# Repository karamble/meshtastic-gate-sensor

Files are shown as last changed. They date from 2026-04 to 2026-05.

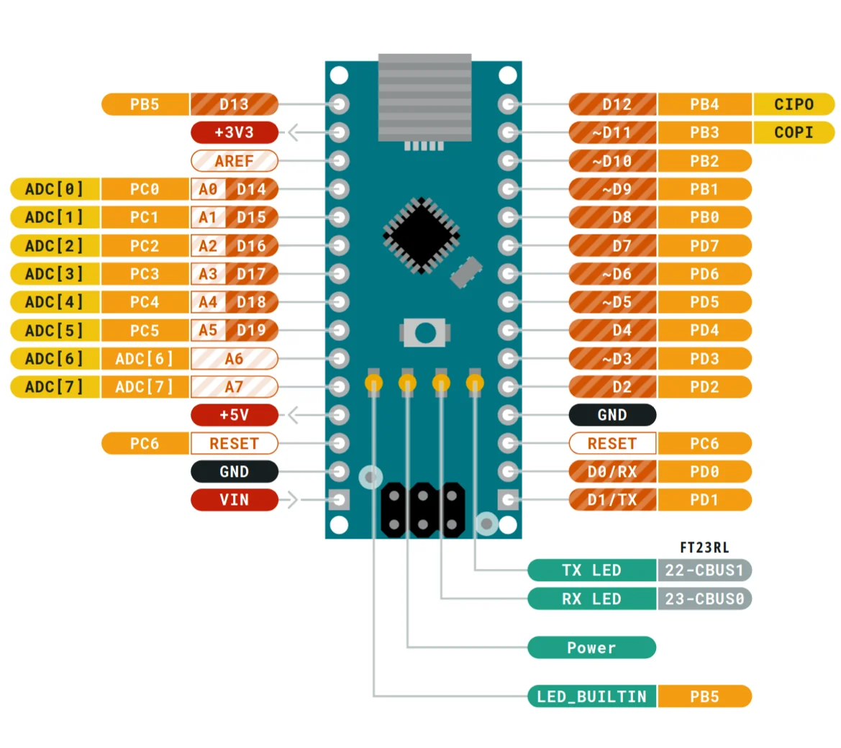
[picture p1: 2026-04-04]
pin-outs/arduino-nano.webp

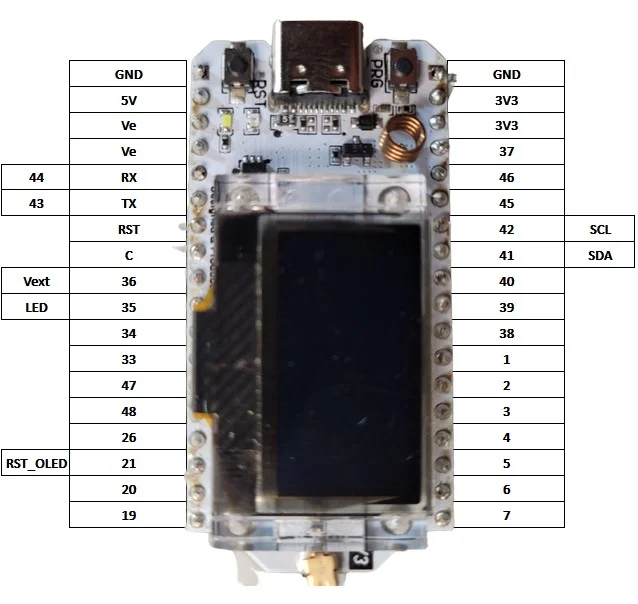
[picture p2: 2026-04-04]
pin-outs/heltecv3.webp

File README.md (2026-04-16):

# Meshtastic Gate & Door Sensor

Carrier board + firmware that bridges a cheap 433 MHz wireless door sensor onto a private Meshtastic LoRa mesh. A trigger on the door raises an event on the mesh — no WiFi, no cloud, no gateway.

## Architecture

```
KERUI D026 (433 MHz) → RXB6 Receiver → Arduino Nano → UART → Heltec LoRa32 V3 → LoRa mesh
```

The 433 MHz sensor broadcasts a fixed code on every open/close event. An Arduino Nano decodes the code with `rc-switch` on D2 (INT0) and forwards a short text line over SoftwareSerial D3 → voltage divider → Heltec GPIO47. The Heltec runs stock Meshtastic with the serial module in `TEXTMSG` mode at 9600 baud and relays each line into the mesh. A 10 s debounce collapses the KERUI retransmit burst into one mesh event per physical opening.

Firmware emits `Gate: TRIGGERED` on every event and `GATE NODE: Online` every 5 minutes as a heartbeat. KERUI D026 sends the same code on open and close, so `CODE_CLOSED` is disabled by default — one code per event is all you get.

Powered by a Waveshare Solar Power Manager D with 2× 18650 batteries and a 6 V 2 W solar panel. Total draw ≈ 105 mA.

## Carrier PCB v2.3

Custom 75×66 mm 2-layer board with:

- Heltec LoRa32 V3 socket (2×18 pins)
- Arduino Nano socket (2×15 pins, 15.24 mm row spacing)
- RXB6 433 MHz receiver (8-pin SIP, direct solder)
- Logic level divider 2.2k / 3.3k (5V → 3.0V on GPIO47)
- Hardening: 10k DE pull-up, 100nF bypass, 100µF bulk
- GND copper pour on both layers
- 0 DRC violations, 34 netlist self-checks pass

Generated programmatically by `pcb/gate_sensor_pcb_v2.py` and validated with KiCad 10.

## Build

Requires Docker (for KiCad CLI) and PlatformIO.

```bash
make help            # show all targets

# PCB
make drc             # design rule check
make fab             # export Gerbers + drill for JLCPCB

# Firmware
make build           # compile
make upload          # flash the Nano
make monitor         # 115200 USB serial monitor
make learn-sensor    # discover a new 433 MHz sensor's code

# Heltec Meshtastic flash & configure (stock firmware)
./scripts/flash-heltec-meshtastic.sh           # defaults (auto-detect, EU_868)
./scripts/flash-heltec-meshtastic.sh --help
```

The flash script downloads the latest stock Meshtastic release, flashes the Heltec V3, applies the gate-sensor config (GPIO47 RX at 9600 baud, TEXTMSG mode, owner name `GateSensor`/`GATE`, GPS disabled, Bluetooth disabled) and verifies every setting before closing.

## Learning a new sensor

If you're using a different 433 MHz sensor than the KERUI D026, discover its code with:

```bash
make learn-sensor
```

Trigger the sensor a few times and watch for repeating `RF unknown: <decimal>` lines. Copy the decimal into `CODE_OPEN` in `firmware/include/config.h`, re-run `make upload`, and the sensor will fire `Gate: TRIGGERED` on the mesh. See [docs/learn-sensor.md](docs/learn-sensor.md) for details.

## Project Structure

```
├── Makefile                      # build targets (KiCad Docker + PlatformIO)
├── pcb/
│   ├── gate_sensor_pcb_v2.py     # PCB generator script
│   ├── gate_sensor_v2.kicad_pcb  # generated board
│   ├── test_netlist.py           # 34-check PCB self-test
│   ├── generate_assembly.py      # 3D assembly view generator
│   └── logo_silk.json            # raccoon logo silkscreen data
├── firmware/
│   ├── platformio.ini            # PlatformIO config (board=nanoatmega328new)
│   ├── src/main.cpp              # bridge firmware
│   └── include/config.h          # sensor codes, pin defs, timing
├── scripts/
│   └── flash-heltec-meshtastic.sh  # Heltec flash + config
├── docs/
│   ├── schematic.md              # schematic + netlist
│   ├── pcb.md                    # PCB design documentation
│   ├── firmware.md               # firmware documentation
│   ├── assembly.md               # assembly and setup guide
│   ├── learn-sensor.md           # discovering a new 433 MHz sensor code
│   ├── bom.md                    # bill of materials
│   └── ordering.md               # JLCPCB ordering guide
└── pin-outs/                     # component pinout reference images
```

## BOM

~$52 total for one complete sensor node. See [docs/bom.md](docs/bom.md) for the full bill of materials.

## License

ISC — see [LICENSE](LICENSE).

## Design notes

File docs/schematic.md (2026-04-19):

# Schematic Description

## Architecture

```
  KERUI D026          RXB6 433MHz        Arduino Nano           Heltec LoRa32 V3
  door sensor         receiver           (ATmega328P)           (Meshtastic)
  +-----------+       +----------+       +----------------+     +----------------+
  | 433 MHz   |~~~~~> | DATA  ---|------>| D2 (INT0)      |     |                |
  | open/close|       | DE <-R5- |--+    |                |     |                |
  +-----------+       | VDD      |  |    | D3 (TX)  ------|--+  |                |
                      | GND      |  |    |                |  |  |                |
                      +----------+  |    | D4 (RX) <------|--|--|- GPIO48 (TX)   |
                                    |    |           5V --|--|--|- 5V            |
                                    |    |          GND --|--|--|- GND           |
                                    |    +----------------+  |  |                |
                                    |                        |  |                |
                                    |    Logic Level Div     |  |                |
                                    |    +------------+      |  |                |
                                    |    | R1 2.2k    |<-----+  |                |
                                    |    |   +--jct---|-------->| GPIO47 (RX)   |
                                    |    | R2 3.3k    |         |                |
                                    |    |   +--GND   |         |                |
                                    |    +------------+         +----------------+
                                    |
  Waveshare Solar     J4 (switch)   |
  Power Mgr D         +-----+       |
  +-----------+  J2   |IN|OUT|------+----> 5V bus
  | 5V OUT  --|------->  |   |
  | GND     --|------>| GND bus
  +-----------+       +-----+
```

## Net List

| Net | Description | Connected Pins |
|-----|---|---|
| GND | Ground | Heltec L1, R1; Nano L4, R14; RXB6 pins 2,3,8; R2 pad2; C1 pad2; C2 pad2; J2 pin2 |
| 5V | Main power bus | Heltec L2; Nano R12 (5V pin); RXB6 pins 4,5 (VDD); R5 pad1; C1 pad1; C2 pad1; J4 pin2 (switch out) |
| 5V_IN | Unswitched input | J2 pin1 (Waveshare 5V); J4 pin1 (switch in) |
| 3V3 | 3.3V (Heltec only) | Heltec R2, R3 (bridged, not distributed) |
| D3 | SoftwareSerial TX | Nano R10 (D3); R1 pad1 |
| D2 | RF DATA | Nano R11 (D2/INT0); RXB6 pin 7 (DATA) |
| HELTEC_RX | Level-shifted serial | R1 pad2; R2 pad1; Heltec L13 (GPIO47) |
| HELTEC_TX | Heltec serial TX (direct, v2.5) | Heltec L14 (GPIO48); Nano R9 (D4) |
| DE | RXB6 data enable | RXB6 pin 6 (DE); R5 pad2 |

**Note on D2 net:** This signal connects to physical pin D2 (L5), which provides INT0 for RCSwitch interrupt-driven reception. The firmware uses `RF_PIN 2` (D2).

## Pin Assignments

### Heltec WiFi LoRa 32 V3 (U3) — 2x18 pins

Left row (L1-L18), top to bottom (USB end to antenna end):

| Pin | Label | Net | Function |
|-----|---|-----|---|
| L1 | GND | GND | Ground |
| L2 | 5V | 5V | Power input (from 5V bus) |
| L3 | Ve | -- | |
| L4 | Ve | -- | |
| L5-L12 | GPIO44,TX43,RST,... | -- | Unused |
| L13 | GPIO47 | HELTEC_RX | **Serial RX** (Meshtastic serial module) |
| L14 | GPIO48 | HELTEC_TX | **Serial TX** (Meshtastic serial module) → Nano D4 (direct, v2.5) |
| L15-L18 | 26,21,20,19 | -- | Unused |

Right row (R1-R18):

| Pin | Label | Net | Function |
|-----|---|-----|---|
| R1 | GND | GND | Ground |
| R2 | 3V3 | 3V3 | 3.3V output (bridged to R3) |
| R3 | 3V3 | 3V3 | 3.3V output |
| R4-R18 | GPIO37-7 | -- | Unused |

**Why GPIO47 instead of GPIO44:** GPIO44 is shared with the CP2102 USB-UART on the Heltec V3. Using GPIO47 (L13) avoids conflict and allows USB serial to remain available for Meshtastic configuration.

### Arduino Nano (U1) — 2x15 pins, 15.24mm (600mil) row spacing

Left row (L1-L15):

| Pin | Label | Net | Function |
|-----|---|-----|---|
| L1 | D1 | -- | |
| L2 | D0 | -- | |
| L3 | RST | -- | |
| L4 | GND | GND | Ground |
| L5 | D2 | D2 | **RF DATA input** (INT0 for RCSwitch) |
| L6 | D3 | D3 | **SoftwareSerial TX** to Heltec |
| L7-L15 | D4-D12 | -- | Unused |

Right row (R1-R15):

| Pin | Label | Net | Function |
|-----|---|-----|---|
| R1-R3 | D13,3V3,REF | -- | |
| R4-R11 | A0-A7 | -- | Unused |
| R12 | 5V | 5V | **Power input** (from 5V bus, not VIN) |
| R13 | RST | -- | |
| R14 | GND | GND | Ground |
| R15 | VIN | -- | **Not connected** (VIN has onboard regulator; shorting to 5V feeds output back to input) |

### RXB6 433MHz Receiver (U2) — 8-pin SIP, direct solder

Two groups of 4 pins at 2.54mm pitch, 25.4mm gap between groups. Module body extends to the right of the pin column.

| Pin | Group | Label | Net | Function |
|-----|---|---|-----|---|
| 1 | 1 | ANT | -- | Antenna (17.3cm wire or SMA) |
| 2 | 1 | GND | GND | Ground |
| 3 | 1 | GND | GND | Ground |
| 4 | 1 | VDD | 5V | Power (5V, not 3.3V) |
| 5 | 2 | VDD | 5V | Power (5V) |
| 6 | 2 | DE | DE | Data Enable (pulled high via R5) |
| 7 | 2 | DATA | D2 | Data output to Nano D2 (INT0) |
| 8 | 2 | GND | GND | Ground |

## Logic Level Divider (5V to 3.3V)

Converts the Nano's 5V SoftwareSerial TX to a safe level for the Heltec's 3.3V GPIO47.

```
  Nano D3 (5V) ──── R1 (2.2k) ────┬──── Heltec GPIO47 (HELTEC_RX)
                                   │
                                R2 (3.3k)
                                   │
                                  GND
```

Output voltage: 5V x 3.3k / (2.2k + 3.3k) = **3.0V** (safe for 3.3V logic input)

## Power Circuit

```
  J2 (Waveshare 5V OUT) ──[5V_IN]──> J4 pin1 (switch IN)
                                           │
                                      [toggle switch]
                                           │
                                      J4 pin2 (switch OUT) ──[5V]──> V5 bus
                                                                        │
                                                    ┌───────────────────┼───────────────┐
                                                    │                   │               │
                                               Heltec L2          Nano R12 (5V)    RXB6 VDD
                                                                                   (pins 4,5)
```

All modules are powered from the switched 5V bus. The Nano is powered via its 5V pin (bypassing its onboard voltage regulator). The RXB6 runs on 5V for better sensitivity.

## Hardening Components

| Ref | Value | Purpose | Placement |
|-----|---|---|---|
| R5 | 10k | DE pull-up to 5V | Between V5 bus and RXB6 pin 6 (DE). Keeps data enable active. |
| C1 | 100nF ceramic | Bypass capacitor | Near RXB6 VDD (pin 4). Filters high-frequency noise on power supply. |
| C2 | 100uF electrolytic | Bulk capacitor | On V5/GND bus near J4 switch. Smooths inrush current and voltage dips. |

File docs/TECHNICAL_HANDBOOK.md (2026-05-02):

# Gate Sensor Technical Handbook

*A reference for builders, modifiers, and the technically curious.*

---

## Table of Contents

1. [System Architecture](#1-system-architecture)
2. [Carrier PCB v2.5](#2-carrier-pcb-v25)
3. [Pin Map](#3-pin-map)
4. [Power](#4-power)
5. [Firmware Architecture](#5-firmware-architecture)
6. [EEPROM Layout](#6-eeprom-layout)
7. [CMD Protocol Wire Reference](#7-cmd-protocol-wire-reference)
8. [Build, Flash, Monitor](#8-build-flash-monitor)
9. [Heltec Flash: Standalone vs Developer Modes](#9-heltec-flash-standalone-vs-developer-modes)
10. [PCB Fabrication and Self-Test](#10-pcb-fabrication-and-self-test)
11. [Modifying the Design](#11-modifying-the-design)
12. [Known Issues and Wishlist](#12-known-issues-and-wishlist)
13. [References](#13-references)

---

## 1. System Architecture

```
KERUI D026          RXB6 433 MHz       Arduino Nano             Heltec LoRa32 V3
door sensor         receiver           (ATmega328P, 5V)         (ESP32-S3 + SX1262)
                                                                running stock Meshtastic
+-----------+       +----------+       +----------------+       +----------------+
| 433 MHz   |~~~~~> | DATA  ---|------>| D2 (INT0)      |       |                |
| open/close|       | DE <-R5- |--+    |                |       |                |
+-----------+       | VDD  5V  |  |    | D3 (TX)  ------|---->| GPIO47 (RX)    |
                    +----------+  |    |                | R1/R2 |                |
                                  |    |                | divider                |
                                  |    | D4 (RX) <------|<------| GPIO48 (TX)    |
                                  |    |   5V     5V/GND|       |  5V / GND      |
                                  |    +----------------+       +----------------+
                                  |                                     |
                              5V bus (J2/J4 fed from Waveshare)         |
                                                                        v
                                                                  LoRa mesh (any region)
```

Everything hangs off a single 5 V rail. The gate sensor's two MCUs talk to each other over a UART that is **bidirectional from PCB v2.5 onwards** — the Nano sends gate events to the Heltec for forwarding to the mesh, and the Heltec's Meshtastic serial module relays inbound `@Gate` commands back to the Nano on GPIO48 → Nano D4. The Heltec runs **stock** Meshtastic firmware; nothing custom is built or flashed on the ESP32-S3 side. The serial module's `TEXTMSG` mode is the integration glue.

The Nano's USB-UART (115200 baud, hardware UART) is independent of the Heltec UART and is used purely for build/upload, debug serial, and 433 MHz sensor learning (`make learn-sensor`).

---

## 2. Carrier PCB v2.5

A 75 × 66 mm two-layer FR-4 board, 1.6 mm thick, 1 oz copper, lead-free HASL. Generated programmatically by `pcb/gate_sensor_pcb_v2.py` — the script writes KiCad S-expressions directly without depending on `pcbnew` or SWIG, so it runs anywhere Python 3 runs. The KiCad file (`pcb/gate_sensor_v2.kicad_pcb`) is the output, not the source.

| Parameter | Value |
|---|---|
| Dimensions | 75 × 66 mm with USB-C notch (X = 10–29, 8 mm deep) |
| Layers | F.Cu / B.Cu |
| Min trace / space | 0.25 mm signal, 0.50 mm power / 0.30 mm |
| Min drill | 0.8 mm |
| Vias | 1.4 mm pad / 0.8 mm drill (22 total) |
| DRC status | 0 violations, 0 unconnected nets |

### Layout summary

```
         10    29
    ┌─────┘    └──────────────────────────┐
    │     USB-C notch (Heltec connector)  │
    │                                     │
    │  U3 Heltec    U2 RXB6   U1 Nano    │  66 mm
    │                                     │
    │  C2   J4-sw              J2-PWR    │
    └─────────────────────────────────────┘
                     75 mm
```

Top half holds the three "modules":

| Ref | Component | Footprint | Notes |
|---|---|---|---|
| **U3** | Heltec LoRa32 V3 | 2×18 socket, 22.86 mm row pitch | Socketed, removable |
| **U1** | Arduino Nano | 2×15 socket, 15.24 mm (600 mil) row pitch | Socketed, removable |
| **U2** | RXB6 433 MHz receiver | 8-pin SIP, 2 groups of 4 with 25.4 mm gap | Direct-soldered, **not** socketed |

Passives sit between the Nano and RXB6:

| Ref | Value | Role |
|---|---|---|
| R1 | 2.2 kΩ | Logic-divider series (Nano D3 → Heltec GPIO47) |
| R2 | 3.3 kΩ | Logic-divider shunt to GND |
| R5 | 10 kΩ | DE pull-up for RXB6 pin 6 (do-not-populate by default; see "BOM" → R5 note) |
| C1 | 100 nF ceramic | RXB6 VDD bypass |
| C2 | 100 µF electrolytic | 5 V bus bulk decoupling |

Connectors at the bottom edge:

| Ref | Type | Role |
|---|---|---|
| J2 | 2-pin 5.08 mm screw terminal | Power in (5 V from Waveshare + GND) |
| J4 | JST-PH 2 mm 2-pin | Power switch in-line with the 5 V bus |

### Logic-level divider

The Nano runs at 5 V; the Heltec's GPIO47 expects 3.3 V logic. A passive divider produces 3.0 V at the Heltec input, well above its V_IH:

```
Nano D3 (5 V) ──── R1 (2.2 kΩ) ────┬──── Heltec GPIO47
                                    │
                                R2 (3.3 kΩ)
                                    │
                                   GND

V_out = 5 V × 3.3 / (2.2 + 3.3) = 3.0 V
```

The **return path** (Heltec GPIO48 → Nano D4) does **not** need a divider — the Heltec drives 3.3 V which the ATmega328P at 5 V VCC happily reads as logic high (V_IH ≥ 3 V at 5 V VCC). PCB v2.4 included a 4.7 kΩ series resistor R6 here as ESD/back-feed protection, but bring-up showed it attenuated the signal below V_IH and dropped received bytes; **v2.5 removed R6** and routes Heltec GPIO48 directly to Nano D4. (See `pcb.md` for the full version history.)

### Routing strategy

- **F.Cu (top):** all signal traces, plus most of the 5 V and GND distribution as 0.50 mm power traces along Y = 56 (V5) / Y = 58 (GND).
- **B.Cu (bottom):** GND drops from each module's GND pin via offset vias, plus the few traces that have to cross F.Cu (notably the V5 feed from J4 that needs to cross the GND bus, and the D2/RF-DATA trace that has to cross D3).
- **GND pours** on both layers, following the board outline including the USB-C notch.

The `pcb/test_netlist.py` self-test checks 34 specific net invariants (no V5/GND short, no VIN-to-5V leakage, R1/R2 divider math is correct, every firmware pin in `config.h` matches the PCB net, etc.) and catches accidental regressions in the Python generator.

### Board renders

- `pcb/output/board.svg` — vector render of all four printable layers
- `pcb/output/board.pdf` — PDF version
- `newpcb.png` — high-resolution photo of an assembled board (top of repo)
- 3D model preview: `make assembly` then `make open-assembly` (requires the KiCad AppImage).

Carrier PCB

---

## 3. Pin Map

Authoritative source for pin assignments: `firmware/include/config.h` for the Nano side; `scripts/flash-heltec-meshtastic.sh` (`serial.rxd`, `serial.txd`) for the Heltec side. The PCB nets are checked against both at build time by `pcb/test_netlist.py`.

### Arduino Nano (U1) — 2 × 15 pins, 15.24 mm row spacing

| Nano pin | Net | Role | Where else it goes |
|---|---|---|---|
| D2 (L5) | `D2` | RF DATA in (INT0 for RCSwitch) | RXB6 pin 7 |
| D3 (L6) | `D3` | SoftwareSerial TX → Heltec | R1 pad 1 (divider input) |
| D4 (L7) | `HELTEC_TX` | SoftwareSerial RX ← Heltec | Heltec GPIO48 (direct, v2.5) |
| 5V (R12) | `5V` | Power in (5 V bus, **not** VIN) | Heltec L2, RXB6 pins 4/5, J4 pin 2 |
| GND (L4, R14) | `GND` | Ground | All module GNDs |
| VIN (R15) | — | **Not connected** — VIN routes to the Nano's onboard regulator and connecting it to the 5 V bus would short the regulator output back to its input |

### Heltec LoRa32 V3 (U3) — 2 × 18 pins

| Heltec pin | Net | Role |
|---|---|---|
| L1 / R1 | `GND` | Ground |
| L2 | `5V` | 5 V power input — Heltec's onboard regulator steps down to 3V3 |
| L13 (GPIO47) | `HELTEC_RX` | Meshtastic serial module RX, fed by Nano D3 through R1/R2 divider |
| L14 (GPIO48) | `HELTEC_TX` | Meshtastic serial module TX, direct to Nano D4 (v2.5) |
| R2 / R3 | `3V3` | Heltec's 3.3 V output (bridged on the carrier; **not** distributed to other modules) |

The Heltec V3 has GPIO44 wired to its CP2102 USB-UART. Using GPIO44 for the Meshtastic serial module would conflict with USB; **GPIO47 is the correct choice**. Likewise `serial.txd` must be set to a usable GPIO that is *not* a strap pin — the flash script uses `48`. **Setting `serial.txd=0` silently kills RX as well**, because GPIO0 is an ESP32-S3 boot strap and the UART driver init fails.

### RXB6 433 MHz receiver (U2)

8-pin SIP, two 4-pin groups with a 25.4 mm gap, body extends right.

| Pin | Label | Net | Role |
|---|---|---|---|
| 1 | ANT | — | 17.3 cm whip or SMA pigtail to bulkhead |
| 2 / 3 / 8 | GND | `GND` | Ground |
| 4 / 5 | VDD | `5V` | Power. **Run on 5 V**, not 3.3 V — better sensitivity, and the DATA output is still 5 V-logic-compatible with Nano D2. |
| 6 | DE | `DE` | Data enable — held high via R5 (10 kΩ pull-up to 5 V). Many RXB6 batches have an internal bias and float high without R5; ours is do-not-populate by default. Populate if your unit doesn't decode without it. |
| 7 | DATA | `D2` | Decoded RF data → Nano D2 (INT0) |

---

## 4. Power

```
USB-C ───┐                                       J4 (toggle switch)
         ↓                                        +-----+
Waveshare Solar Power Mgr D              J2       |     |
  +---------------------+                          |     |
  | USB-C in            |                          |     |
  | Solar in (optional) +─── 5V_IN ───── pin1 ────| IN  |
  | 3 × 18650 cells     +─── GND ──────────────|  | OUT +─── 5V bus
  | 5 V boost converter |                       |  +-----+
  +---------------------+                       |     │
                                               (J4 pin 2 is the bus
                                                feed; everything
                                                downstream is on
                                                switched 5 V)
```

The Waveshare Solar Power Manager D has three input paths to its boost converter / charger, any of which can keep the system running:

- **USB-C** — the default for indoor / bench / development use.
- **18650 cells** — three in parallel, 3000 mAh each. Charged from either USB-C or solar; discharged to power the system when neither is supplying current.
- **Solar panel (optional)** — a 6 V panel into the Waveshare's solar input keeps the batteries topped up for outdoor installs. Not part of the kit; source any 6 V panel with a compatible connector.

| Quantity | Value |
|---|---|
| Total system draw | ~105 mA at 5 V (Heltec dominates) |
| Battery capacity | 3 × 18650 3000 mAh ≈ 9 Ah @ 3.7 V ≈ 33 Wh |
| Battery-only runtime (no USB / no solar) | ~85 hours |
| Solar input on a clear midday (typical 6 V 2 W panel) | ~330 mA at 6 V |

No charging circuitry on the carrier board; everything is offloaded to the Waveshare. C2 (100 µF) on the carrier smooths inrush at switch-on; C1 (100 nF) bypasses the RXB6 VDD specifically.

The 5 V bus is **switched by J4** — flip the toggle and everything downstream loses power instantly. There is no soft-shutdown sequence; the Nano's EEPROM writes are atomic at the byte level so this is safe in practice.

---

## 5. Firmware Architecture

The Nano firmware lives in `firmware/`. Build system: PlatformIO (`firmware/platformio.ini`):

```ini
[env:nano]
platform = atmelavr
board = nanoatmega328new        # optiboot bootloader, 115200 baud — clone Nanos
framework = arduino
monitor_speed = 115200
lib_deps =
    sui77/rc-switch@^2.6.4
```

Source map:

| File | Role |
|---|---|
| `firmware/src/main.cpp` | Everything: setup/loop, RF, EEPROM, CMD parser, ACK emission |
| `firmware/include/config.h` | Compile-time constants (pin assignments, defaults, EEPROM addresses) |

### Boot sequence (`setup()`)

1. **Disable the watchdog** (`wdt_disable()`). Optiboot leaves WDT enabled with its last value after a watchdog reset; not clearing it would re-trigger an immediate reset.
2. Bring up USB serial at 115200 (debug echo) and SoftwareSerial at 9600 (Meshtastic).
3. `rf.enableReceive(digitalPinToInterrupt(RF_PIN))` — RCSwitch hooks INT0 on D2.
4. **Bootcount**: read 16-bit counter from EEPROM, treat `0xFFFF` (fresh chip) as 0, increment, write back.
5. **Heartbeat config**: read `hbEnabled` (byte) and `hbIntervalMin` (byte). Out-of-range or `0xFF` → defaults (`true`, 30 min).
6. **Debounce config**: same pattern, defaults to 10 s.
7. **Hit counter**: read 32-bit value; `0xFFFFFFFF` → 0.
8. **Code registry**: load 16 × 4 B codes and the parallel 16 × 16 B name table from EEPROM. Empty slot sentinel `0xFFFFFFFF`. **If the registry is completely empty**, seed slot 0 with `DEFAULT_CODE_OPEN` (= `150910`, KERUI D026 factory code) so out-of-the-box installs work without a `CODE_ADD`.
9. `delay(8000)` — give the Heltec time to boot and open its Meshtastic serial module before sending the first byte. Sending earlier drops bytes into a closed UART.
10. Emit the boot STATUS frame.

### Main loop (`loop()`)

Three responsibilities, run round-robin every iteration:

#### RF event handling

```c
if (rf.available()) {
    unsigned long code = rf.getReceivedValue();
    rf.resetAvailable();

    unsigned long debounceMs = (unsigned long)debounceSec * 1000UL;
    if (code != 0) {
        int8_t idx = codeIndexOf((uint32_t)code);
        if (idx >= 0) {
            // Known code — per-code debounce
            if ((now - codeLastEvent[idx]) > debounceMs) {
                codeLastEvent[idx] = now;
                hitCount++;
                saveHitCount();
                sendTriggered((uint32_t)code, codeNames[idx]);
            }
        } else if ((now - lastUnknownEvent) > debounceMs) {
            // Unknown code — single global debounce
            lastUnknownEvent = now;
            char buf[64];
            snprintf(buf, sizeof(buf), "RF unknown: %lu", code);
            Serial.println(buf);                                // USB only
            if (code >= UNKNOWN_MIN_CODE) {
                sendTriggered((uint32_t)code, "unknown");        // mesh
            }
        }
    }
}
```

Two key design choices:

- **Per-code debounce**: each registered code has its own `codeLastEvent[]` slot. Two physically separate sensors (e.g. front gate + back gate) firing within the same 10 s window both get reported. Without per-code debounce, a back-gate event right after a front-gate event would be silently swallowed.
- **Unknown codes share a single global debounce window** to keep 433 MHz noise from flooding the mesh. A code below `UNKNOWN_MIN_CODE` (= 1000) is logged on USB only — those are essentially noise from cheap remotes, weather stations, etc. Above 1000, it is broadcast as `Gate: TRIGGERED:<code> unknown` for the operator's `CODE_ADD`.

#### Inbound CMD handling — `pollCmd()`

Drains SoftwareSerial RX into `cmdBuf[]` byte-by-byte. On `\n` (line terminator), the line is dispatched to `processCmdLine()`. Buffer overflow (line longer than `CMD_BUF_SIZE` = 80 B) discards the partial line to avoid mis-parsing a truncation.

`processCmdLine()` does the unusual heavy lifting that the gate sensor inherits from Meshtastic's serial-module behaviour: when a remote node broadcasts text, the Heltec's serial module emits it on GPIO48 prefixed with the **sender's short name** and `: `, e.g. `1e44: @Gate STATUS`. The parser skips past any `<anything>: ` prefix, then looks for the `@` addressing token.

```c
static void processCmdLine(char* line) {
    char* at = strchr(line, '@');
    if (!at) return;                      // not addressed at us
    line = at;
    char* space = strchr(line + 1, ' ');
    if (!space) return;                   // no verb
    *space = '\0';
    const char* target = line + 1;        // "Gate" / "ALL" / "Other"
    char* rest = space + 1;
    while (*rest == ' ') rest++;

    char* colon = strchr(rest, ':');
    const char* param = NULL;
    if (colon) { *colon = '\0'; param = colon + 1; }
    const char* verb = rest;
    if (*verb == '\0') return;
    handleCommand(target, verb, param);
}
```

`handleCommand()` then case-insensitively matches `target` against `ALL` and `SENSOR_NAME` (= `"Gate"`), and dispatches the verb. Unknown verbs are silently ignored (no NACK spam on the mesh).

#### Periodic STATUS heartbeat

```c
if (hbEnabled && (now - lastStatus >= (unsigned long)hbIntervalMin * 60000UL)) {
    lastStatus = now;
    sendStatus();
}
```

Default 30 minutes. Resets on `HB_INTERVAL` change so the next STATUS comes `<minutes>` from the command, not from when the previous interval would have fired.

### Outbound message helpers

| Helper | Format |
|---|---|
| `sendStatus()` | `Gate: STATUS: Mode:ARMED Scan:GATE Hits:%lu Temp:0.0C Up:%02u:%02u:%02u Type:GATESENSOR Boot:%u` |
| `sendTriggered(code, name)` | `Gate: TRIGGERED:%lu %s` (`%s` is `name`, `"unnamed"` if null/empty, or `"unknown"` for unregistered codes) |
| `sendAck(verb, status)` | `Gate: %s_ACK:%s` |
| `sendCodeList()` | `Gate: CODES:<code>=<name>,…` or `Gate: CODES:NONE` |
| `sendMessage(buf)` | echoes `buf` to **both** SoftwareSerial (mesh) and USB serial (debug) |

### Why this firmware can't ever support DMs

Meshtastic 2.5+ encrypts direct messages end-to-end with PKI. The Heltec's SerialModule in `TEXTMSG` mode is the only path to GPIO48 the Nano can listen on, and that path is broadcast-only by design — DMs never reach the UART. There is no firmware change on the Nano that recovers them; the bytes have already been discarded by the SerialModule.

To support DMs you'd need to switch the Heltec to `PROTO` mode (binary protobuf payloads) and replace the Nano with a chip big enough to host the [Meshtastic-arduino](https://github.com/meshtastic/Meshtastic-arduino) library — the ATmega328P's 2 KB SRAM is too tight. An XIAO ESP32-S3 (or the Heltec's own ESP32 if you just merge the two MCUs) would be a comfortable fit. We have not done this and have no near-term plans to.

---

## 6. EEPROM Layout

ATmega328P has 1 kB EEPROM. Layout below; everything not listed is reserved (read as `0xFF` from a virgin chip).

| Address | Size | Field | Notes |
|---|---|---|---|
| 0–1 | 2 B (`uint16_t`) | `bootCount` | Increments once per `setup()`. Fresh `0xFFFF` → 0. |
| 2 | 1 B (`uint8_t`) | `hbEnabled` | `0xFF`/`1` = on, `0` = off. Mutated by `HB_ON` / `HB_OFF`. |
| 3 | 1 B | `hbIntervalMin` | Minutes (1–60). `0xFF` or out-of-range → `DEFAULT_HB_MIN` = 30. Mutated by `HB_INTERVAL`. |
| 4 | 1 B | `debounceSec` | Seconds (1–60). `0xFF` or out-of-range → `DEFAULT_DEBOUNCE_SEC` = 10. Mutated by `DEBOUNCE_SET`. |
| 5 | 1 B | reserved | |
| 6–9 | 4 B (`uint32_t`) | `hitCount` | Cumulative trigger count. `0xFFFFFFFF` → 0. Mutated on every TRIGGERED event and by `HITS_RESET`. |
| 10–11 | 2 B | reserved | |
| 12–75 | 64 B | `codes[16]` × `uint32_t` | Registered RF codes. `0xFFFFFFFF` = empty slot. Mutated by `CODE_ADD` / `CODE_REMOVE` / `CODE_CLEAR`. |
| 76–331 | 256 B | `codeNames[16]` × 16 B | Parallel name table. First byte `0xFF` or `0x00` = unnamed. |

Writes use `EEPROM.put` and `EEPROM.update`, both of which skip cells whose value already matches — unchanged bytes don't burn write cycles. ATmega328P EEPROM is rated for 100 k writes per cell. The hit counter is the most-written cell at one write per trigger; at ~10 triggers/day, the cell will outlast the rest of the hardware.

`saveNameSlot(idx)` rewrites only one of the 16 name slots so a `CODE_ADD` doesn't churn the entire 256 B name table.

---

## 7. CMD Protocol Wire Reference

### Wire format

```
@<target> <verb>[:<param1>[:<param2>...]]\n
```

- `<target>`: case-insensitive match against `ALL` or `SENSOR_NAME` (default `"Gate"`).
- `<verb>`: uppercase. Unknown verbs are silently dropped.
- `<params>`: colon-delimited.
- `\n` terminates a line. The parser strips an optional leading `<anything>: ` prefix (which the Meshtastic SerialModule prepends in `TEXTMSG` mode with the sender's short name).

The reply, when there is one, takes the form:

```
Gate: <VERB>_ACK:<status>\n
```

…except for `STATUS` (the STATUS frame itself is the reply) and `CODE_LIST` (a single-line `Gate: CODES:…` frame).

### Verb table

| Verb | Param | EEPROM addr touched | ACK / reply | Notes |
|---|---|---|---|---|
| `STATUS` | — | none | (`STATUS` frame) | On-demand heartbeat |
| `HB_ON` | — | 2 | `HB_ACK:OK` | Re-enable periodic STATUS |
| `HB_OFF` | — | 2 | `HB_ACK:OK` | Suspend periodic STATUS (boot + on-demand still fire) |
| `HB_INTERVAL` | `<1-60>` | 3 | `HB_ACK:OK` / `HB_ACK:ERROR` | Restarts the timer |
| `REBOOT` | — | none | `REBOOT_ACK:OK`, then watchdog reset | New STATUS arrives ~10 s later, `Boot:` incremented |
| `HITS_RESET` | — | 6 | `HITS_RESET_ACK:OK` | Zero the persistent counter |
| `DEBOUNCE_SET` | `<1-60>` | 4 | `DEBOUNCE_ACK:OK` / `DEBOUNCE_ACK:ERROR` | Per-code and global windows both use this |
| `CODE_ADD` | `<code>[:<name>]` | 12-75, 76-331 | `CODE_ACK:OK` / `UPDATED` / `EXISTS` / `FULL` / `ERROR` | Code in `[1, 16777215]` (24-bit). Name 1–15 chars `[A-Za-z0-9_-]`. |
| `CODE_REMOVE` | `<code>` | 12-75, 76-331 | `CODE_ACK:OK` / `NOT_FOUND` / `ERROR` | |
| `CODE_LIST` | — | none | `CODES:<c>=<n>,…` or `CODES:NONE` | Single text frame, not an ACK |
| `CODE_CLEAR` | — | 12-75, 76-331 | `CODE_ACK:OK` | Wipes registry |

### CODE_ADD result semantics

```c
enum CodeAddResult { CODE_ADDED, CODE_UPDATED, CODE_EXISTS, CODE_FULL };

CodeAddResult codeAddOrUpdate(uint32_t c, const char* name);
```

| Result | Wire ACK | When |
|---|---|---|
| `CODE_ADDED` | `OK` | New code, new slot |
| `CODE_UPDATED` | `UPDATED` | Code already registered, but the supplied name differs from the stored one — the name is overwritten |
| `CODE_EXISTS` | `EXISTS` | Code already registered, no name change needed (caller passed no name, or the same name) |
| `CODE_FULL` | `FULL` | All 16 slots taken |

`ERROR` is emitted before `codeAddOrUpdate()` is called, when the code is out of range or the name fails `nameValid()` (only `[A-Za-z0-9_-]`, 1–15 chars).

### Identity invariant

The target-matching code assumes the Heltec's Meshtastic owner short-name matches the Nano's `SENSOR_NAME`. The flash script sets `--set-owner-short "GATE"`; if you ever change `SENSOR_NAME` you must re-flash the Heltec with the matching owner. TEXTMSG mode strips envelope metadata so the Nano cannot discover the Heltec's short-name at runtime.

---

## 8. Build, Flash, Monitor

```bash
make build           # PlatformIO compile
make upload          # Flash the Nano (auto-detect FTDI port by VID:PID)
make monitor         # USB serial at 115200 baud
make learn-sensor    # Same monitor, with a banner explaining how to read it
make clean           # PlatformIO clean
```

### Nano port auto-detection

The Makefile resolves the Nano's USB port by FTDI VID:PID through the `/dev/serial/by-id/` symlinks:

```make
NANO_PORT = $(shell \
  ports=$$(ls /dev/serial/by-id/usb-FTDI_FT232R_USB_UART_*-if00-port0 2>/dev/null); \
  count=$$(echo "$$ports" | grep -c .); \
  if [ "$$count" -eq 0 ]; then echo "NANO_NOT_FOUND"; \
  elif [ "$$count" -gt 1 ]; then echo "MULTIPLE_NANOS"; \
  else echo "$$ports"; fi)
```

This **avoids ever flashing the wrong device** when both the Nano (FTDI FT232R) and the Heltec (Silicon Labs CP2102) are plugged into the same host. If two FTDI Nanos are co-plugged, the upload bails with `MULTIPLE_NANOS` and asks you to set `upload_port` manually.

### Bootloader gotcha

Modern clone Nanos ship with **optiboot** at 115200 baud, not the legacy bootloader at 57600. `platformio.ini` MUST be:

```ini
board = nanoatmega328new      # optiboot, 115200
```

…not `nanoatmega328` (legacy, 57600). Using the wrong one produces "stk500_recv: programmer is not responding" on every upload.

### Debug serial

`make monitor` opens the Nano's USB UART at 115200. The firmware echoes every mesh-bound message there too, and prints `RF unknown: <decimal>` for any 433 MHz code that wasn't already registered. This is the same stream `make learn-sensor` uses.

---

## 9. Heltec Flash: Standalone vs Developer Modes

The Heltec runs **stock** Meshtastic. `scripts/flash-heltec-meshtastic.sh` automates flash + post-flash configuration, downloads the latest stock release via `gh`, and verifies every setting before exiting.

The script has two modes that differ only in PSK and Bluetooth handling:

| Setting | Default mode (developer) | `--standalone` (retail) |
|---|---|---|
| Channel PSK | private 256-bit from `.env`'s `MESH_PSK` | factory default LongFast `AQ==` |
| Bluetooth | disabled | enabled (default) |
| LoRa region | EU_868 (or `-r`) | EU_868 (or `-r`) |
| GPS | NOT_PRESENT | NOT_PRESENT |
| Serial module | GPIO47 RX / GPIO48 TX, 9600 baud, TEXTMSG | same |
| Owner long / short | GateSensor / GATE | same |
| `.env` `MESH_PSK` required | yes | no |
| Verification step | asserts PSK ≠ `AQ==`, BLE = false | asserts PSK = `AQ==`, BLE = true |

### Running it

```bash
# Connect Heltec via USB-C, put in boot mode (hold BOOT, press+release RST, release BOOT)

./scripts/flash-heltec-meshtastic.sh                    # developer / private mesh (needs .env)
./scripts/flash-heltec-meshtastic.sh --standalone       # retail / public LongFast

# Common flags (work in both modes)
./scripts/flash-heltec-meshtastic.sh -r US              # different region
./scripts/flash-heltec-meshtastic.sh -p /dev/ttyUSB1    # specific port
./scripts/flash-heltec-meshtastic.sh -v v2.7.15.567b8ea # specific Meshtastic release
./scripts/flash-heltec-meshtastic.sh --flash-only       # firmware only, no config
./scripts/flash-heltec-meshtastic.sh --config-only      # config only, skip firmware
./scripts/flash-heltec-meshtastic.sh --confirm-config   # read back & verify; no writes
```

Or via Make:

```bash
make flash-heltec-standalone
```

### What the config step actually does

For each setting, the script invokes `meshtastic --port <port> --set <key> <value>`:

- `lora.region`
- (`--standalone` skipped) `--ch-set psk "$MESH_PSK" --ch-index 0`
- `position.gps_mode NOT_PRESENT`
- `telemetry.device_update_interval 1800`
- `serial.enabled true`, `serial.echo false`, `serial.rxd 47`, `serial.txd 48`, `serial.baud BAUD_9600`, `serial.timeout 0`, `serial.mode TEXTMSG`
- `--set-owner GateSensor --set-owner-short GATE`
- (`--standalone` skipped) `bluetooth.enabled false`

The `serial.txd 48` is **load-bearing** — see the comment block at line 482 of the script. `txd 0` would silently kill RX too, because GPIO0 is an ESP32-S3 boot strap pin and the UART driver init fails when handed it. GPIO48 is unused on the carrier and safe.

### Why two modes exist

- **Developer/private**: when you're testing a unit on your bench mesh, or assembling for a customer who wants their unit pre-tied to their existing private mesh, you want a 256-bit PSK already loaded and BLE off (BLE has measurable idle current and you don't need it for USB-attached config).
- **Standalone/retail**: a unit going to a first-time buyer should ship on the public LongFast channel so the buyer can see it on any stock Meshtastic node out of the box, and BLE should be **on** so the buyer can pair with the Meshtastic mobile app and migrate to a private PSK themselves. The user handbook is written for this state.

---

## 10. PCB Fabrication and Self-Test

### Self-test before fab

```bash
make test-netlist
```

Runs `pcb/test_netlist.py`, which checks 34 invariants on the generated `.kicad_pcb` file directly:

- Net membership: every pad is on the right net
- Forbidden connections: no V5 / GND short, no VIN / 5V short
- Firmware ↔ PCB consistency: every `RF_PIN` / `SERIAL_TX` / `SERIAL_RX` constant in `config.h` resolves to the right Nano pad
- Voltage divider math: R1 = 2.2k, R2 = 3.3k, divider output is 3.0 V
- Trace continuity: no orphan stubs

A regression in the Python generator that, say, swaps two pads, fails this test before you ever upload Gerbers to a fab. CI should run `make drc && make test-netlist` on every PR that touches `pcb/`.

### Generate fabrication files

```bash
make drc        # runs KiCad's DRC; pcb/output/drc_report.json must show 0 violations
make fab        # gerbers + drill -> pcb/output/
```

Behind the scenes:

```bash
docker run --rm -v $(pwd):/work kicad/kicad:10.0 kicad-cli pcb export gerbers ...
```

…using the official KiCad 10 Docker image, no host KiCad install required.

Zip the contents of `pcb/output/` and upload to JLCPCB. The full ordering walkthrough — recommended JLCPCB option settings, when to use lead-free HASL, how to suppress the JLCJLCJLC mark — is in `docs/ordering.md`.

### Other PCB targets

| Target | Output |
|---|---|
| `make svg` | `pcb/output/board.svg` (vector) |
| `make pdf` | `pcb/output/board.pdf` |
| `make pcb-stats` | board statistics report |
| `make assembly` | `pcb/gate_sensor_v2_assembly.kicad_pcb` with 3D models loaded |
| `make assembly-step` | `pcb/output/assembly_3d.step` (3D STEP for mechanical / case design) |
| `make open` | open the bare PCB in KiCad's GUI (requires the AppImage) |
| `make open-assembly` | open the assembly view with 3D models in KiCad's GUI |

---

## 11. Modifying the Design

### Adding a new sensor type

`SENSOR_NAME` and `SENSOR_TYPE` in `config.h` are the only knobs that need to change to spin a different sensor (motion, window, generic door, …) off the same hardware:

```c
#define SENSOR_NAME "MotionHall"     // mesh prefix, also the @target token
#define SENSOR_TYPE "MOTION"          // STATUS frame's Type: field
```

Downstream parsers that classify nodes by sensor type read **`SENSOR_TYPE`**, not the prefix — so adding `WINDOW`, `GARAGE`, `MAIL`, or any other type doesn't require dispatcher changes anywhere else.

If you change `SENSOR_NAME`, **also update the Heltec's owner short name** to match, otherwise CMD targeting will not work — `flash-heltec-meshtastic.sh` line 491 (`--set-owner-short "GATE"`) is the place. The user handbook walks the buyer through this implicitly by saying "the gate sensor is named `GateSensor`/`GATE` on the mesh"; if you've rebranded, update that text too.

### Adding a new CMD verb

The dispatch is a flat `if (strcasecmp(verb, "X") == 0)` chain in `handleCommand()` (`firmware/src/main.cpp:265-363`). Add a branch:

```c
if (strcasecmp(verb, "MY_VERB") == 0) {
    // ... do thing ...
    sendAck("MY_VERB", "OK");
    return;
}
```

Update `docs/firmware.md` and the user/technical handbooks. For verbs that mutate state, persist to EEPROM (use `EEPROM.update` so unchanged bytes don't burn cycles) and reserve an address in [§6](#6-eeprom-layout).

### Bumping `MAX_CODES`

`MAX_CODES` is currently 16. Each registered code costs 4 B in EEPROM (`codes`) + 16 B in `codeNames` + 4 B in RAM (`codeLastEvent`). Going to 32 codes:

- +16 × 4 B = 64 B in EEPROM `codes` (still well within 1 kB)
- +16 × 16 B = 256 B more in EEPROM `codeNames` — pushes the table past byte 587, still fine
- +16 × 4 B = 64 B more RAM (`codeLastEvent` is `unsigned long[]`)

ATmega328P has 2 kB SRAM. Watch the linker map (`.pio/build/nano/firmware.elf.size`) — once you're above ~1.6 kB of statics you'll start getting stack-overflow miscompiles in the snprintf hot paths. The current build sits at ~470 B static + 410 B globals.

### Regenerating the PCB after a footprint change

The PCB is fully generated:

```bash
cd pcb
python3 gate_sensor_pcb_v2.py    # rewrites gate_sensor_v2.kicad_pcb
cd ..
make drc                          # confirm 0 violations
make test-netlist                 # confirm 34/34 checks pass
make fab                          # if you're going to fab
```

`pcb/test_netlist.py` will catch a footprint regression that breaks a net before DRC will. Treat both as required.

### Switching to a different RF receiver

The RXB6 footprint is 8-pin SIP, two 4-pin groups, 25.4 mm gap. If you swap to a different module (e.g. an SRX882 or a CC1101 module), you'll likely need:

1. New footprint in the Python generator
2. Verify pin 4/5 are 5V-tolerant on the new module (or move it onto 3V3 — the Nano's D2 input still reads a 3.3 V high as logic high)
3. If the new module needs SPI rather than a single DATA line, the firmware needs new RX library code; RCSwitch is OOK-only

For OOK 433 MHz alternatives (which most cheap remotes use), a drop-in module that exposes a DATA pin will work with the existing RCSwitch code; only the footprint changes.

---

## 12. Known Issues and Wishlist

- **DM dead-end** (commit `924fb3d`). DMs are PKI-encrypted by Meshtastic 2.5+ and never reach GPIO48; the gate sensor cannot respond to a DM. The user handbook calls this out; any downstream tool that wants to send commands programmatically must rewrite DMs into broadcasts with the `@Gate` prefix prepended before sending.
- **No real temperature**. The STATUS frame's `Temp:0.0C` is a placeholder kept for STATUS-frame format compatibility. ATmega328P's internal temperature sensor is not accurate enough to be worth wiring up; if we ever want a real temperature, an external sensor (DS18B20 on a free Nano pin) is the right path. Currently no plans.
- **Unknown-code threshold is build-time only.** `UNKNOWN_MIN_CODE` (= 1000) is `#define`d in `config.h`. A `THRESHOLD_SET:<n>` verb would be cheap to add and would let operators tune the noise floor at runtime; the only reason it isn't there is that no one has needed it yet.
- **Per-code debounce vs. global**. The current per-code design is correct for "two physical gates triggered close together" but means a single sensor that retransmits its code 4–10 times *and* has a sister-sensor on the same code would re-fire. We have not seen this in practice.
- **Watchdog rollover**. `millis()` rolls over after ~49.7 days; the firmware uses `(now - last) > window` which is correctly wrap-safe via unsigned arithmetic, but no integration test confirms this. If you see exactly-49-day weirdness, this is the suspect.
- **Public-LongFast retail flow vs the developer-PSK flow**. The user handbook describes a unit shipped via `--standalone`; the developer flow flashes a private PSK + BLE-off. We expect the manufacturing line to default to `--standalone` once we have first sales — the only thing standing in the way is sourcing a sane MESH_PSK story for builders who *do* want a private mesh.

---

## 13. References

### Inside this repo

- [`README.md`](../README.md) — project overview and quick start
- [`docs/USER_HANDBOOK.md`](USER_HANDBOOK.md) — buyer-facing handbook
- [`docs/bom.md`](bom.md) — bill of materials and cost
- [`docs/pcb.md`](pcb.md) — PCB design reference (longer-form than [§2](#2-carrier-pcb-v25))
- [`docs/schematic.md`](schematic.md) — full netlist and pin assignments
- [`docs/firmware.md`](firmware.md) — full firmware reference
- [`docs/assembly.md`](assembly.md) — soldering, post-solder checks, bench/field test
- [`docs/learn-sensor.md`](learn-sensor.md) — discovering a new 433 MHz sensor's code over USB
- [`docs/ordering.md`](ordering.md) — JLCPCB order form walkthrough
- [`firmware/src/main.cpp`](../firmware/src/main.cpp) — the firmware itself
- [`firmware/include/config.h`](../firmware/include/config.h) — compile-time constants
- [`scripts/flash-heltec-meshtastic.sh`](../scripts/flash-heltec-meshtastic.sh) — Heltec automation
- [`pcb/gate_sensor_pcb_v2.py`](../pcb/gate_sensor_pcb_v2.py) — PCB generator
- [`pcb/test_netlist.py`](../pcb/test_netlist.py) — 34-check self-test
- [`Makefile`](../Makefile) — top-level build/flash/test targets

### External

- Meshtastic firmware: <https://github.com/meshtastic/firmware>
- Meshtastic CLI: <https://meshtastic.org/docs/software/python/cli/>
- rc-switch library: <https://github.com/sui77/rc-switch>
- KERUI D026 product page: search "KERUI D026 433MHz door sensor"
- Heltec WiFi LoRa 32 V3: <https://heltec.org/project/wifi-lora-32-v3/>
- Waveshare Solar Power Manager D: <https://www.waveshare.com/solar-power-manager-d.htm>

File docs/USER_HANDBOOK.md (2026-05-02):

# Gate Sensor User Handbook

*A wireless door/gate sensor that talks to your Meshtastic network — no WiFi, no cloud, no gateway.*

---

## Table of Contents

1. [What Is This?](#1-what-is-this)
2. [What's in the Box](#2-whats-in-the-box)
3. [First Boot](#3-first-boot)
4. [Out of the Box: The Public Mesh](#4-out-of-the-box-the-public-mesh)
5. [Going Private](#5-going-private)
6. [Pairing Your Sensor](#6-pairing-your-sensor)
7. [Commanding the Sensor Over the Mesh](#7-commanding-the-sensor-over-the-mesh)
8. [What You'll See on the Mesh](#8-what-youll-see-on-the-mesh)
9. [Tuning for Your Environment](#9-tuning-for-your-environment)
10. [Mounting and Power](#10-mounting-and-power)
11. [Region and Regulatory](#11-region-and-regulatory)
12. [Troubleshooting](#12-troubleshooting)
13. [Cheat Sheet](#13-cheat-sheet)
14. [Where to Go Next](#14-where-to-go-next)

---

## 1. What Is This?

The **Gate Sensor** is a small, solar-powered device that turns a cheap 433 MHz door/gate sensor into a message on your Meshtastic LoRa network. When the door opens, the sensor on the door radios a 433 MHz pulse; the gate sensor unit picks it up and broadcasts a short text line into the mesh. Any Meshtastic node — your phone, a tablet, another Heltec on a desk — sees the event arrive within a second or two.

```
KERUI D026 (433 MHz) → gate sensor unit → LoRa mesh → your phone/laptop/other node
```

There is no WiFi, no cloud, no gateway server. The gate sensor talks straight to your Meshtastic devices over LoRa. It runs from a USB-C power supply, from its three 18650 batteries, or — for self-charging outdoor installs — from an optional solar panel.

The device ships ready to use on the **public Meshtastic LongFast channel** — the same default channel every stock Meshtastic node uses out of the box. You can put it to work in five minutes, then switch it to your own private channel whenever you're ready.

Gate sensor PCB

---

## 2. What's in the Box

A complete kit contains:

- **Gate sensor unit** — Heltec LoRa32 V3 + Arduino Nano + RXB6 433 MHz receiver assembled on a 75 × 66 mm carrier PCB, mounted in a 3D-printed enclosure.
- **KERUI D026 door sensor** — the small magnetic sensor that goes on the door/gate itself. Includes its own coin-cell battery.
- **Waveshare Solar Power Manager D** — a battery board that handles solar charging and provides a stable 5 V to the gate sensor. Holds three 18650 cells.
- **Three 18650 lithium-ion cells** (3000 mAh each) — installed in the Waveshare board. They provide several days of battery autonomy in darkness.
- **Antenna** — 433 MHz whip for the RXB6, plus a LoRa antenna for the Heltec.

If you assembled the unit yourself from the BOM (see [`docs/bom.md`](bom.md)), the same applies — you just sourced the parts separately.

You will also need:

- A **6 V solar panel** (2 W or larger) to keep the batteries charged. **Not included** — source any 6 V panel with a 2 m or longer lead and a connector compatible with your Waveshare board's solar input.
- A second Meshtastic device — typically a phone running the **Meshtastic mobile app** (Android or iOS). Pairing the app over Bluetooth is the easiest way to interact with the gate sensor and also the easiest way to switch to a private channel later.
- A small Phillips screwdriver (J2 power-in screw terminal).

---

## 3. First Boot

1. **Mount the antennas.** Screw the LoRa antenna onto the Heltec's gold SMA jack (the one on top). Connect the 433 MHz antenna to the bulkhead SMA on the case — this one feeds the RXB6 receiver.
2. **Drop the 18650s into the Waveshare board.** Mind the polarity printed on the board.
3. **Power the Waveshare board.** Pick whichever input fits your install:
   - **USB-C** — plug a 5 V USB-C charger into the Waveshare's USB-C port. Easiest for indoor / bench / first-boot use.
   - **Solar** — connect a 6 V solar panel (not included; source separately) to the Waveshare's solar input. Right for outdoor self-charging installs.
   - **Batteries only** — the Waveshare will run from the 18650s alone if you've already charged them; you can power up the gate sensor first and connect USB or solar later.
4. **Wire the Waveshare 5 V output to the gate sensor's J2 screw terminal.** Two wires, marked `5V` and `GND` on the PCB silk. Don't get them backwards — the boards have no reverse-polarity protection.
5. **Flip the power switch on J4.** The Heltec's small OLED screen lights up; you'll see the Meshtastic logo briefly, then the node summary screen.

The first STATUS frame goes out about 8 seconds after power-on. That delay is intentional — it gives the Heltec's Meshtastic firmware time to come up and open its serial module before the Arduino Nano on board starts talking to it.

What you should see arriving in your Meshtastic app within ~10 seconds of power-on:

```
Gate: STATUS: Mode:ARMED Scan:GATE Hits:0 Temp:0.0C Up:00:00:08 Type:GATESENSOR Boot:1
```

If you see that, the gate sensor is alive and on the mesh. The fields are explained in [§8](#8-what-youll-see-on-the-mesh); for now, just confirm the message arrives.

---

## 4. Out of the Box: The Public Mesh

The unit ships joined to the **default Meshtastic public channel**. This channel is called **LongFast**, has the well-known PSK `AQ==`, and uses your region's default LoRa settings (EU_868 unless we sold you a unit configured for a different region).

What this means in practice:

- Pair any stock Meshtastic node — phone with the Meshtastic app, a Heltec on your desk, an existing node you already use — to the **LongFast** channel and the same region as your gate sensor. You will see a node appear in the app called **GateSensor** (short name `GATE`).
- Any STATUS heartbeat or TRIGGERED event the gate sensor emits is visible on that channel.
- You can send commands to the gate sensor (see [§7](#7-commanding-the-sensor-over-the-mesh)) over that channel.

Quick smoke test:

1. Fire up the Meshtastic app on your phone, pair it over Bluetooth to a Meshtastic device tuned to LongFast (or use the gate sensor itself — see "Bluetooth pairing" below).
2. Walk over to the door the KERUI D026 is on and open it.
3. Within ~1 second, a message arrives on the LongFast channel:

   ```
   Gate: TRIGGERED:150910 unnamed
   ```

   `150910` is the factory-calibrated KERUI D026 code. The word `unnamed` is exactly what it looks like: you haven't given the sensor a friendly name yet. We fix that in [§7](#7-commanding-the-sensor-over-the-mesh).

### Bluetooth pairing the gate sensor's Heltec to your phone

Because the unit ships with Bluetooth on, you can pair the gate sensor's Heltec directly to the Meshtastic mobile app:

1. Open the Meshtastic app, tap **+** → **Add a device** → **Bluetooth**.
2. Pick **GateSensor** (or `GATE` short-name) from the list.
3. Confirm the pairing PIN shown on the Heltec's OLED.

You now own the gate sensor's Heltec from the app. From here you can read its status, change channel settings, and — most importantly — generate a private PSK ([§5](#5-going-private)).

> **Heads-up — public-channel privacy.** While you're on the LongFast channel, *anyone* within LoRa range running a stock Meshtastic device on LongFast will see your gate events. That's fine for testing. It is not what you want for the long term. Move to a private PSK as soon as you're comfortable with the device.

---

## 5. Going Private

A private channel is just a public channel with a different PSK (pre-shared key). Every Meshtastic node that knows the same PSK can read messages on that channel; nodes without it see only encrypted noise.

We recommend using the Meshtastic mobile app for this — it's the lowest-friction path.

### From the mobile app (recommended)

1. Pair the gate sensor's Heltec to the app over Bluetooth (see [§4](#4-out-of-the-box-the-public-mesh)).
2. **Channels → Primary**. The primary channel is the default broadcast channel — the one the gate sensor emits its events on.
3. Tap **Generate New** (or **Randomize**) on the PSK field. Confirm. The app sends the new PSK to the gate sensor and reboots its radio.
4. **Share** the same channel — use the app's QR code share. Any other Meshtastic device that scans the QR (or imports the channel URL) joins the same private mesh.
5. Apply the QR/URL to every Meshtastic node you want on this private mesh — your phone, a tablet, another base station.

That's it. The gate sensor still sends `Gate: TRIGGERED:…` exactly as before, but now only nodes carrying your PSK can read the broadcast.

### From a USB-tethered laptop

If you'd rather use the command line:

```bash
# Plug the gate sensor's Heltec USB-C into your laptop. Then:
meshtastic --port /dev/ttyUSB0 --ch-set psk random --ch-index 0 --info
```

The `--info` at the end prints back the new channel config including the new PSK. Copy the channel URL (the line beginning with `https://meshtastic.org/e/#…`) and import it into every other node you own.

### Verifying you're really private

Ask the device for its current channel info:

```bash
meshtastic --port /dev/ttyUSB0 --info
```

Find the `psk:` line. If it reads `AQ==` you are still on the public channel. Anything else is private.

Or in the mobile app: **Channels → Primary** — the PSK field shows a 32-byte base64 string (much longer than `AQ==`).

> **Don't lose your PSK.** If your only copy of the private PSK is on a phone that breaks, you're locked out of your own mesh and will need to USB-flash the gate sensor and every other node. Save the channel URL/QR somewhere safe.

---

## 6. Pairing Your Sensor

The unit ships with the **factory KERUI D026 code** (decimal `150910`) already registered. If your kit included a KERUI D026 from us, no pairing is required — just open the door and the mesh shows `Gate: TRIGGERED:150910 unnamed`.

If you want to:

- **Give the existing sensor a friendly name** — see [§7, "Naming a sensor"](#naming-a-sensor).
- **Add another KERUI D026** (or any other 433 MHz door sensor) as a second sensor — see "Learning a new sensor" below.
- **Use a different 433 MHz sensor entirely** — also "Learning a new sensor."

### Learning a new sensor

The gate sensor unit listens for any 433 MHz code, not just the factory one. To teach it about a new sensor:

1. **Be within ~10–30 m of the gate sensor** with the new sensor in your hand.
2. **Trigger the new sensor 4–5 times** over a few seconds. (For a KERUI D026, that's open-close-open-close-open.)
3. Watch your Meshtastic app — any unknown 433 MHz code at or above the noise floor shows up like this:

   ```
   Gate: TRIGGERED:8675309 unknown
   ```

   The decimal number is your sensor's code. The word `unknown` is the placeholder name the firmware uses for codes it has never seen registered.

4. **Register the code** with a friendly name:

   ```
   @Gate CODE_ADD:8675309:backgate
   ```

   The reply lands on the same mesh channel: `Gate: CODE_ACK:OK`. From now on, triggers from that sensor read `Gate: TRIGGERED:8675309 backgate`.

You can register up to **16 distinct codes**. Names can be 1–15 characters of letters, digits, `_`, or `-`. Spaces, colons, and `@` are not allowed in names.

### Naming a sensor

The factory KERUI ships unnamed because we don't know which door it'll go on:

```
@Gate CODE_ADD:150910:frontdoor
```

Reply: `Gate: CODE_ACK:UPDATED` (since the code was already registered, the gate sensor just updated its name).

You can re-name a sensor later by re-issuing `CODE_ADD` with the same code and a different name.

> **Why some codes don't show up.** Random radio noise on 433 MHz produces stray decoded numbers below 1000. The firmware suppresses those on the mesh (you don't want every microwave oven nearby to flood your mesh) but any code 1000 or higher gets broadcast. If your sensor has a very low code, register it explicitly with `CODE_ADD` from a USB connection and it will start firing — see the technical handbook for that path.

---

## 7. Commanding the Sensor Over the Mesh

You talk to the gate sensor by sending plain-text commands on the **same broadcast channel** the gate sensor reports on. The format is:

```
@Gate VERB[:param[:param2]]
```

The `@Gate` prefix tells the gate sensor "this is for me." (You can use `@ALL` instead — the gate sensor will respond to that too.) The reply arrives a moment later on the same channel:

```
Gate: VERB_ACK:OK
```

> **Important — broadcasts only.** The gate sensor processes commands sent on the **broadcast channel only**. **Direct messages are a structural dead-end** and are silently dropped before the gate sensor's firmware ever sees them. This is a deliberate constraint in the underlying Meshtastic serial-module design — there is no way around it short of a hardware change. Always send commands on the channel, never as a DM.

Both sides — the command you send and the ACK you get back — are visible to anyone else on the channel (which, after [§5](#5-going-private), is just you and your own nodes).

### Sensor codes (the registry)

Adding, removing, listing, and clearing the 433 MHz codes the gate sensor will treat as door events:

| Command | Effect | Reply |
|---|---|---|
| `@Gate CODE_LIST` | Show all registered codes and their names. | `Gate: CODES:150910=frontdoor,8675309=backgate` (or `CODES:NONE` if empty) |
| `@Gate CODE_ADD:<code>:<name>` | Register a new code (max 16 codes). Name is optional but recommended; 1–15 chars of letters/digits/`_`/`-`. | `Gate: CODE_ACK:OK` (added) / `UPDATED` (existing code, name changed) / `EXISTS` (already registered with same name) / `FULL` (all 16 slots used) / `ERROR` (bad code or bad name) |
| `@Gate CODE_REMOVE:<code>` | Unregister a code. | `Gate: CODE_ACK:OK` / `NOT_FOUND` / `ERROR` |
| `@Gate CODE_CLEAR` | Wipe the entire registry. **Destructive.** | `Gate: CODE_ACK:OK` |

All registry changes are persisted to non-volatile EEPROM and survive reboots and power loss.

### Status and runtime tuning

| Command | Effect | Reply |
|---|---|---|
| `@Gate STATUS` | Force an immediate STATUS heartbeat right now. | (the STATUS frame itself — see [§8](#8-what-youll-see-on-the-mesh)) |
| `@Gate HB_ON` | Turn periodic STATUS heartbeats back on. | `Gate: HB_ACK:OK` |
| `@Gate HB_OFF` | Stop periodic STATUS heartbeats. (Boot STATUS and on-demand STATUS still fire.) | `Gate: HB_ACK:OK` |
| `@Gate HB_INTERVAL:<minutes>` | Change the heartbeat interval. Range: 1–60 minutes. Default: 30. | `Gate: HB_ACK:OK` / `ERROR` |
| `@Gate DEBOUNCE_SET:<seconds>` | Change the RF debounce window. Range: 1–60 seconds. Default: 10. | `Gate: DEBOUNCE_ACK:OK` / `ERROR` |
| `@Gate HITS_RESET` | Zero out the lifetime trigger counter shown in STATUS. | `Gate: HITS_RESET_ACK:OK` |
| `@Gate REBOOT` | Watchdog-reboot the gate sensor's Nano. The Heltec is unaffected. New STATUS arrives ~10 seconds later with `Boot:` incremented. | `Gate: REBOOT_ACK:OK` (then a short silence, then a new STATUS) |

All settings are persisted to EEPROM. They survive reboots and battery swaps.

### Examples

```
@Gate STATUS                   → Gate: STATUS: Mode:ARMED Scan:GATE Hits:42 …
@Gate CODE_LIST                → Gate: CODES:150910=frontdoor
@Gate CODE_ADD:8675309:back    → Gate: CODE_ACK:OK
@Gate CODE_ADD:8675309:back    → Gate: CODE_ACK:EXISTS
@Gate CODE_ADD:8675309:rear    → Gate: CODE_ACK:UPDATED
@Gate CODE_REMOVE:8675309      → Gate: CODE_ACK:OK
@Gate CODE_REMOVE:404          → Gate: CODE_ACK:NOT_FOUND
@Gate HB_INTERVAL:5            → Gate: HB_ACK:OK
@Gate DEBOUNCE_SET:30          → Gate: DEBOUNCE_ACK:OK
@Gate HITS_RESET               → Gate: HITS_RESET_ACK:OK
@Gate REBOOT                   → Gate: REBOOT_ACK:OK (then a fresh STATUS)
```

---

## 8. What You'll See on the Mesh

The gate sensor emits three kinds of frames. All three are plain text broadcasts on the channel.

### STATUS heartbeat

```
Gate: STATUS: Mode:ARMED Scan:GATE Hits:42 Temp:0.0C Up:03:17:55 Type:GATESENSOR Boot:7
```

| Field | Meaning |
|---|---|
| `Gate:` | Instance prefix. Always the same; lets you spot the gate sensor's frames in a busy channel. |
| `STATUS:` | Frame type. |
| `Mode:ARMED` | Always `ARMED` in this firmware. Reserved for a future DISARMED state. |
| `Scan:GATE` | What kind of RF traffic this sensor is watching for. |
| `Hits:42` | Lifetime count of door triggers since the last `HITS_RESET` (or since the device was made). |
| `Temp:0.0C` | Placeholder. The gate sensor has no temperature probe; the field exists for compatibility with the Meshtastic node-status format. |
| `Up:03:17:55` | Uptime since the last reboot, as `HH:MM:SS`. |
| `Type:GATESENSOR` | Sensor class. Other devices in the same product family may report `MOTION`, `DOOR`, etc. |
| `Boot:7` | Number of times the gate sensor has booted in its life. Increments on every power-on or `REBOOT`. |

A STATUS arrives:

- **Once at boot**, ~8 seconds after power-on.
- **Periodically** (every 30 minutes by default — adjustable with `HB_INTERVAL`).
- **Whenever you ask** for one with `@Gate STATUS`.

You can suppress periodic STATUS broadcasts entirely with `@Gate HB_OFF`. Boot STATUS and on-demand STATUS still fire.

### TRIGGERED event

```
Gate: TRIGGERED:150910 frontdoor
```

One of these is emitted every time the door is opened (after the debounce window — see [§9](#9-tuning-for-your-environment)). The number is the 433 MHz code; the trailing word is the name you assigned. Three special trailing words:

- A **registered name** you set with `CODE_ADD` (`frontdoor`, `back`, `garage`).
- `unnamed` — the code is registered but you never gave it a name.
- `unknown` — the code is not in the registry but is loud enough to be a real transmitter (≥ 1000), so the firmware reports it anyway. This is your hook for [learning a new sensor](#6-pairing-your-sensor).

### ACKs

A reply to a command, e.g. `Gate: CODE_ACK:OK` or `Gate: HB_ACK:ERROR`. Always follows the form:

```
Gate: <VERB>_ACK:<status>
```

`<status>` is `OK`, `ERROR`, or a verb-specific value (`UPDATED`, `EXISTS`, `FULL`, `NOT_FOUND`). The full table is in [§7](#7-commanding-the-sensor-over-the-mesh).

---

## 9. Tuning for Your Environment

Two settings are worth thinking about. Both are runtime-changeable; both persist across reboots.

### Heartbeat interval (`HB_INTERVAL`)

How often the gate sensor sends a STATUS frame "I'm still alive." Default: 30 minutes.

- **Lower** (1–10 min): you find out faster if the gate sensor goes offline. Trade-off: more LoRa airtime, slightly more power draw.
- **Higher** (30–60 min): less airtime. Trade-off: longer worst-case "is it still up?" gap.

```
@Gate HB_INTERVAL:5     → STATUS every 5 minutes
@Gate HB_INTERVAL:60    → STATUS once an hour
@Gate HB_OFF            → no periodic STATUS (boot + on-demand only)
```

### Debounce window (`DEBOUNCE_SET`)

Cheap 433 MHz door sensors are designed to be loud and unreliable: they retransmit the same code 4–10 times in a quick burst whenever the door opens, in case some of the bursts are lost. The gate sensor's job is to collapse that burst into **one** message on your mesh.

The debounce window says "after I see code X, ignore further copies of X for the next *N* seconds." Default: 10 seconds.

- If you see **multiple TRIGGERED messages for one open**, raise the window: `@Gate DEBOUNCE_SET:30`.
- If you have a sensor that legitimately fires often (e.g. a tripwire that pulses every couple of seconds), lower it: `@Gate DEBOUNCE_SET:1`. You probably want a higher value, not lower, in nearly all real installs.

The debounce is **per-code**, so two different sensors firing at the same time both get reported.

---

## 10. Mounting and Power

### The gate sensor unit

The gate sensor unit lives in a 3D-printed enclosure. **The printed case is not weatherproof — mount the unit indoors.** If you need to install it outdoors, swap the printed case for an IP-rated junction box (a 150 × 100 × 70 mm IP65 box is listed in the BOM as the recommended option).

Place it within **10–30 m line-of-sight of the door sensor**. 433 MHz penetrates plaster and wood reasonably well, but is mediocre through brick, metal, and reinforced concrete. If your gate is on the far side of a brick wall, expect to be on the lower end of that range.

The LoRa antenna (Heltec) and the 433 MHz antenna (RXB6) should both have clear airspace. They do not interfere with each other in normal use.

### The KERUI D026

This goes on the door itself. Two pieces:

1. The transmitter body — usually screwed to the door frame.
2. The magnet — screwed to the door, lined up with the transmitter so the gap is < 15 mm when the door is closed.

When the magnet moves away (door opens), the KERUI fires its 433 MHz code. The same code fires on close — the gate sensor cannot tell open from close on this model. If you need open-vs-close distinction, you would need a sensor whose firmware emits two distinct codes; we don't currently ship one.

### Power: USB-C, batteries, or optional solar

The Waveshare Solar Power Manager D charges and balances the three 18650 cells. Power can come from any of:

- **USB-C** plugged into the Waveshare board — the easiest option for indoor or bench use.
- **The 18650 cells alone** — once charged, they keep the unit running on their own.
- **A 6 V solar panel (optional, not included)** wired into the Waveshare's solar input — for outdoor self-charging installs.

Approximate budget at our default settings:

| Quantity | Value |
|---|---|
| Total system draw | ~105 mA at 5 V |
| Battery capacity | 3× 3000 mAh in parallel = ~9000 mAh @ 3.7 V (~33 Wh) |
| Battery-only runtime in total darkness | ~85 hours |
| Solar input (clear day, panel directly facing sun, midday) | ~330 mA at 6 V (well above draw) |

If you choose to add a solar panel, position it with no shade between ~10:00 and ~14:00 local solar time. South-facing in the Northern Hemisphere, north-facing in the Southern. Even a thin tree branch crossing the panel halves output. In winter at high latitudes, plan for the panel to be aimed steeply, kept clean, and ideally not shaded — or step up to a larger panel.

---

## 11. Region and Regulatory

Your unit ships configured for **EU_868** — the European LoRa band — by default. If we sold you a unit for a different region (US, AS_923, ANZ, …) it'll already be set correctly.

If you need to change region (e.g. you're moving the unit between regions, or you bought a generic unit and need to set region for the first time), the easiest path is the Meshtastic mobile app once you've Bluetooth-paired it: **Radio Configuration → LoRa → Region**. Choose the right region for where the device is *physically located* and tap **Save**. The Heltec reboots and rejoins the mesh with the new region.

> **The two radios use different bands.** The 433 MHz door-sensor side is the 433 MHz ISM band, which is license-free across most of the world for low-power devices and is independent of the LoRa region setting. The LoRa side is what the region setting controls. Don't confuse the two.

If you're outside the EU and want to verify regional compliance for the 433 MHz side, the KERUI D026 is sold worldwide; in nearly all jurisdictions it sits in a license-free ISM allocation.

---

## 12. Troubleshooting

### No STATUS frame after power-on

- Check the OLED on the Heltec. If it's dark, the unit isn't powered: verify J4 (power switch) is on, the polarity on J2 is right (`5V` to `5V`, `GND` to `GND`), and the Waveshare's output LEDs are lit.
- The first STATUS comes ~8 seconds after power-on, not immediately. Wait a full 30 seconds before declaring it broken.
- Make sure the Meshtastic node you're watching from is on the **same channel** (LongFast for fresh units, your private channel afterwards) and the **same region**.

### No TRIGGERED message when I open the door

- Check the door sensor's battery. Most "non-working" KERUIs have a dead battery shipped from the factory.
- Trigger the sensor 5–6 times in a row to make sure you're not just hitting the debounce window.
- Watch the mesh while you trigger. If you see `Gate: TRIGGERED:<somenumber> unknown`, your sensor's code isn't registered — `CODE_ADD` it (see [§6](#6-pairing-your-sensor)). If you see *nothing*, you're either out of 433 MHz range, the antenna is disconnected, or the receiver is dead — see "Range and antennas" below.

### Multiple TRIGGERED messages for one door open

The debounce window is too short. Raise it: `@Gate DEBOUNCE_SET:30`.

### A node I expected to see the gate sensor on doesn't

- Same channel? Same region? Same PSK? After [§5](#5-going-private), every node needs the new PSK.
- Distance: LoRa is good but not magic. Concrete buildings, metal roofs, dense foliage all attenuate the signal. If you're at the edge of range, set the gate sensor's `HB_INTERVAL` to 5 minutes for a while and walk around to find dead spots.

### I changed the PSK and now I can't reach the gate sensor

This usually means one node got the new PSK and the others didn't. Pick the device with the new PSK, share its channel URL/QR to every other node. If you've fully lost contact with the gate sensor, USB-tether its Heltec to a laptop and run:

```bash
meshtastic --port /dev/ttyUSB0 --info
```

— that always works regardless of channel state. From there you can re-set the PSK or factory-reset.

### Range and antennas

Both antennas should be hand-tight on their SMA connectors. If you ever transport the unit, screw them off first — antennas under transport vibration can damage their connectors.

The 433 MHz whip should be roughly vertical. The LoRa antenna also wants to be vertical for omnidirectional coverage. Mount the case so neither antenna is right next to a metal surface.

### "I see numbers in the mesh I don't recognize"

If you see an occasional `Gate: TRIGGERED:<code> unknown` and the door wasn't opened, the gate sensor caught a stray 433 MHz transmission from somewhere — a neighbour's car remote, a weather station, a cheap toy. Ignore it; it'll probably never recur. If it recurs reliably and isn't yours, raise the debounce window so it can't flood you, or live with it as background.

### I want to start over

`@Gate CODE_CLEAR` wipes the 433 MHz code registry. To wipe all settings (including the heartbeat and debounce values), the path is to USB-tether and run a clean re-flash — see the technical handbook for that procedure.

---

## 13. Cheat Sheet

### Most-used commands

```
@Gate STATUS                          force a status frame
@Gate CODE_LIST                       show all registered sensors
@Gate CODE_ADD:<code>:<name>          register a sensor
@Gate CODE_REMOVE:<code>              unregister a sensor
@Gate HB_INTERVAL:<minutes>           change heartbeat (1–60)
@Gate DEBOUNCE_SET:<seconds>          change debounce (1–60)
@Gate HITS_RESET                      zero the trigger counter
@Gate REBOOT                          reboot the Nano (~10 s)
```

### Frame shapes

```
Gate: STATUS: Mode:ARMED Scan:GATE Hits:N Temp:0.0C Up:HH:MM:SS Type:GATESENSOR Boot:K
Gate: TRIGGERED:<code> <name>
Gate: <VERB>_ACK:<status>
```

### Defaults

| Setting | Default |
|---|---|
| Heartbeat interval | 30 min |
| Debounce window | 10 s |
| Max registered codes | 16 |
| Channel (out of the box) | LongFast (public) |
| Region (out of the box) | EU_868 (or as ordered) |
| Owner long name | GateSensor |
| Owner short name | GATE |

### Limits

- Code must be a positive decimal between 1 and 16,777,215 (24-bit).
- Names are 1–15 characters, letters / digits / `_` / `-` only. No spaces, colons, or `@`.
- Up to 16 codes registered at any time.

---

## 14. Where to Go Next

- **[Technical Handbook](TECHNICAL_HANDBOOK.md)** — for builders, modifiers, and the technically curious. Covers the firmware architecture, the PCB, EEPROM layout, the wire format of the CMD protocol, build instructions, and how to extend the firmware (new sensor types, new commands, more codes).
- **[BOM](bom.md)** — full bill of materials and rough costs.
- **[Assembly](assembly.md)** — if you have a kit to solder.

If something in this handbook is wrong, unclear, or out of date, please open an issue on the project repository — the gate sensor is open hardware and open firmware, and patches are welcome.

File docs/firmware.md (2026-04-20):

# Firmware Documentation

## Overview

The firmware runs on the Arduino Nano (ATmega328P) and acts as a bridge between the 433MHz RF receiver and the Meshtastic LoRa mesh network. It decodes gate open/close events from the KERUI D026 sensor via the RXB6 receiver and forwards text messages over UART to the Heltec LoRa32 V3 running Meshtastic.

## Project Structure

```
firmware/
  platformio.ini      PlatformIO project config
  include/
    config.h          Sensor codes, pin definitions, timing
  src/
    main.cpp          Main firmware (setup + loop)
```

## Build Environment

- **Framework:** Arduino
- **Platform:** Atmel AVR (`atmelavr`)
- **Board:** `nanoatmega328` (Arduino Nano, ATmega328P, CH340 USB-UART)
- **Build system:** PlatformIO (via Make wrapper)

## Libraries

| Library | Version | Purpose |
|---|---|---|
| rc-switch | ^2.6.4 | 433MHz RF protocol decoding. Uses hardware interrupt INT0 on pin D2. |
| SoftwareSerial | built-in | UART TX on D3 to Heltec (9600 baud) via R1/R2 divider; RX on D4 direct from Heltec GPIO48 (v2.5). |

## Pin Configuration

Defined in `firmware/include/config.h`:

| Define | Value | Function |
|---|---|---|
| `RF_PIN` | 2 | RXB6 DATA input. D2 = INT0 (required by RCSwitch `enableReceive`). |
| `SERIAL_TX` | 3 | SoftwareSerial TX to Heltec GPIO47 via level divider. |
| `SERIAL_RX` | 4 | SoftwareSerial RX ← Heltec GPIO48 (Meshtastic serial TX, direct trace as of v2.5). |

**Note on GPIO47:** The Heltec V3 Meshtastic serial module must be configured to use GPIO47 as its RX pin. GPIO44 is shared with the CP2102 USB-UART and causes conflicts.

## Configuration

Edit `firmware/include/config.h` before building:

### Sensor Codes

The firmware holds up to `MAX_CODES` (default 16) 433 MHz codes in a runtime-mutable list persisted in EEPROM. Codes are added, removed, listed, and cleared over the mesh via the `CODE_*` commands (see the [CMD Protocol](#cmd-protocol) section). An RF frame that matches **any** registered code fires `Gate: TRIGGERED:<code>`.

```c
#define DEFAULT_CODE_OPEN 150910  // factory seed (KERUI D026); 0 disables auto-seeding
#define MAX_CODES         16      // max distinct sensor codes
```

On a fresh chip (all EEPROM code slots `0xFFFFFFFF`), the firmware seeds the list with `DEFAULT_CODE_OPEN` so an out-of-the-box install still detects the calibrated KERUI D026 without any CMDs. To learn a new sensor, use `make learn-sensor` (the production firmware prints every unrecognised code to USB serial as `RF unknown: <decimal>`) and then register the decimal via `@Gate CODE_ADD:<decimal>`.

### Sensor Identity

| Define | Default | Description |
|---|---|---|
| `SENSOR_NAME` | `"Gate"` | Instance prefix on every frame — `Gate: STATUS: ...`, `Gate: TRIGGERED`. Mirrors AntiHunter's `AH34:` pattern so AH-format parsers find the id. |
| `SENSOR_TYPE` | `"GATESENSOR"` | Uppercase sensor-class identifier written into the STATUS frame's `Type:` field. DigiNode CC classifies nodes by this value, not by the prefix, so a future `MotionHall` build can ship `SENSOR_TYPE "MOTION"` without any dispatcher changes. |

### Timing

| Define | Default | Description |
|---|---|---|
| `DEFAULT_HB_MIN` | 30 | Default heartbeat interval in minutes (compile-time fallback). The effective interval is runtime-configurable via the `HB_INTERVAL` command and persisted in EEPROM. |
| `HB_MIN_MIN` / `HB_MIN_MAX` | 1 / 60 | Accepted range for `HB_INTERVAL`. Values outside the range are rejected with `HB_ACK:ERROR`. |
| `DEFAULT_DEBOUNCE_SEC` | 10 | Default RF debounce window (seconds). Collapses the KERUI retransmit burst (4–10 copies per trigger) into one mesh event per physical opening. Runtime-configurable via `DEBOUNCE_SET:<seconds>` and persisted in EEPROM. |
| `DEBOUNCE_MIN_SEC` / `DEBOUNCE_MAX_SEC` | 1 / 60 | Accepted range for `DEBOUNCE_SET`. Values outside the range are rejected with `DEBOUNCE_ACK:ERROR`. |

### EEPROM

| Addr | Size | Purpose |
|---|---|---|
| 0–1 | 2 B (`uint16_t`) | `bootCount` — incremented once per `setup()`. A fresh `0xFFFF` resets to 0. |
| 2 | 1 B (`uint8_t`) | `hbEnabled` — `0xFF`/`1`=on, `0`=off. Mutated by `HB_ON`/`HB_OFF`. |
| 3 | 1 B (`uint8_t`) | `hbIntervalMin` — heartbeat interval (minutes). `0xFF` or out-of-range → `DEFAULT_HB_MIN`. Mutated by `HB_INTERVAL`. |
| 4 | 1 B (`uint8_t`) | `debounceSec` — RF debounce window (seconds). `0xFF` or out-of-range → `DEFAULT_DEBOUNCE_SEC`. Mutated by `DEBOUNCE_SET`. |
| 5 | 1 B | reserved |
| 6–9 | 4 B (`uint32_t`) | `hitCount` — persistent RF trigger counter. `0xFFFFFFFF` (fresh chip) treated as 0. Mutated on every TRIGGERED event and by `HITS_RESET`. |
| 10–11 | 2 B | reserved |
| 12–75 | 64 B | `codes[16]` × `uint32_t` — registered 433 MHz codes. `0xFFFFFFFF` = empty slot. Mutated by `CODE_ADD`/`CODE_REMOVE`/`CODE_CLEAR`. |

Writes use `EEPROM.put`/`EEPROM.update` so unchanged bytes don't consume write cycles. At ATmega328P's 100k-write endurance and an expected write rate of ~10 triggers/day, the hit counter cell will outlast the rest of the hardware.

## Message Format

All messages are sent as plain text over SoftwareSerial at 9600 baud. Meshtastic receives them as TEXTMSG via its serial module.

### STATUS Heartbeat (on boot + every 30 minutes)

```
Gate: STATUS: Mode:ARMED Scan:GATE Hits:3 Temp:0.0C Up:00:15:32 Type:GATESENSOR Boot:5
```

The frame matches the AntiHunter STATUS regex used by CC PRO
(`meshtastic-rewrite.parser.ts:10`) and is also recognised by DigiNode CC's
sensor classifier. The `Type:` field is the authoritative sensor-class
identifier — DigiNode CC ignores the prefix and classifies purely on this
value, so future sensor variants (DOOR, WINDOW, MOTION) can classify without
any backend changes.

| Field | Source | Notes |
|---|---|---|
| `Gate:` | `SENSOR_NAME` | Instance prefix |
| `STATUS:` | literal | AH regex anchor |
| `Mode:ARMED` | constant | AH-required. Reserved for future DISARMED state. |
| `Scan:GATE` | constant | AH-required. Identifies what kind of RF traffic this sensor watches for. |
| `Hits:<n>` | in-RAM counter | Cumulative count of RF triggers since boot |
| `Temp:0.0C` | placeholder | AH-required field; Nano has no accurate temperature sensor |
| `Up:HH:MM:SS` | `millis() / 1000` | Uptime since last boot |
| `Type:GATESENSOR` | `SENSOR_TYPE` | Sensor-class identifier (the extensibility hook) |
| `Boot:<n>` | EEPROM `uint16_t` | Cumulative boot count across power cycles |

### Gate Events

```
Gate: TRIGGERED:<decimal>
```

A single event is emitted per physical trigger. The debounce window (default 10 s, `DEBOUNCE_SET` configurable) collapses the KERUI retransmit burst into one mesh message. The `<decimal>` is the decoded 433 MHz code, enabling correlation against `CODE_LIST` to identify which physical sensor fired. Event frames do not classify a node on their own — DigiNode CC relies on the node having already been classified via a prior STATUS broadcast.

### Unknown RF Codes (debug output only, not sent to mesh)

```
RF unknown: 1234567
```

Printed to the Nano's USB serial (115200 baud) only, not forwarded to Meshtastic. Used by `make learn-sensor` to discover the decimal code for a new sensor.

## CMD Protocol

The Nano listens for command frames on its SoftwareSerial RX pin (D4, fed directly by Heltec GPIO48 as of PCB v2.5). Commands are plain text forwarded by the Heltec's Meshtastic serial module in `TEXTMSG` mode.

> **Broadcasts only — DMs are a structural dead end.**
>
> Since Meshtastic firmware 2.5, direct messages are PKI-encrypted end-to-end and the SerialModule's `TEXTMSG` path is built around channel broadcasts only — a DM addressed to the gate-Heltec's nodeNum **never gets written to GPIO48**, so the Nano sees zero bytes for it. There is no firmware or wiring change on the Nano side that can recover those packets; the SerialModule has already discarded them.
>
> Every command must therefore be sent as a **mesh broadcast** carrying the `@Gate` (or `@ALL`) addressing prefix in the payload. The Nano's `processCmdLine` filter does the per-sensor dispatch (see [Wire format](#wire-format) below). DigiNode CC's `handleSendChatMessage` already auto-rewrites a DM addressed to a `gatesensor` node into a broadcast with the `@<ShortName>` prefix prepended, so the chat UI just works — but any third-party tool talking to a gatesensor must do the same rewrite itself.
>
> If you ever need true DM support on the sensor (e.g. for one-of-many fan-out), the only path is switching the Heltec to `PROTO` mode and replacing the Nano with an MCU big enough to host the [Meshtastic-arduino](https://github.com/meshtastic/Meshtastic-arduino) library and its nanopb buffers — the ATmega328P's 2 KB SRAM is too tight. An XIAO ESP32-S3 or similar would be a comfortable fit.

### Wire format

```
@<target> <verb>[:<param1>[:<param2>...]]\n
```

- `<target>` — `ALL` for broadcast, or the sensor's identity. Matched case-insensitively against `SENSOR_NAME` (default `"Gate"`), so `@Gate`, `@GATE`, and `@gate` all hit.
- `<verb>` — uppercase command name.
- `<params>` — colon-delimited.
- Terminated by `\n` (TEXTMSG preserves the payload's line framing).

Frames that don't begin with `@` are ignored. Frames whose target doesn't match `ALL` or `SENSOR_NAME` are ignored — the sensor will not respond on another node's behalf.

### Identity invariant

The target-matching code assumes the Heltec's Meshtastic owner short-name is the same string as the Nano's `SENSOR_NAME`. This is set by `scripts/flash-heltec-meshtastic.sh` (`--set-owner-short "GATE"`) and must be kept in sync if `SENSOR_NAME` ever changes. TEXTMSG mode strips envelope metadata, so the Nano cannot discover the Heltec's short-name at runtime.

### Commands

| Verb | Params | ACK | Effect |
|---|---|-----|---|
| `STATUS` | none | *(none — the STATUS frame itself is the reply)* | Emits the STATUS heartbeat frame on demand. |
| `HB_ON` | none | `Gate: HB_ACK:OK` | Enables periodic STATUS broadcasts. Persisted. |
| `HB_OFF` | none | `Gate: HB_ACK:OK` | Suspends periodic STATUS broadcasts. Boot STATUS and `@… STATUS` queries still work. Persisted. |
| `HB_INTERVAL` | `<minutes>` in `[1, 60]` | `Gate: HB_ACK:OK` or `HB_ACK:ERROR` | Changes the heartbeat interval and restarts the timer so the next STATUS fires `<minutes>` from the command. Persisted. |
| `REBOOT` | none | `Gate: REBOOT_ACK:OK` (emitted before reset) | Watchdog-triggered reset. The Nano comes back in ~1 s and re-emits the boot STATUS with `Boot:` incremented. |
| `HITS_RESET` | none | `Gate: HITS_RESET_ACK:OK` | Zeros the persistent hit counter. |
| `DEBOUNCE_SET` | `<seconds>` in `[1, 60]` | `Gate: DEBOUNCE_ACK:OK` or `DEBOUNCE_ACK:ERROR` | Changes the RF event debounce window. Persisted. |
| `CODE_ADD` | `<decimal>` in `[1, 16777215]` (24-bit) | `Gate: CODE_ACK:OK` / `CODE_ACK:EXISTS` / `CODE_ACK:FULL` / `CODE_ACK:ERROR` | Adds a 433 MHz code to the match list. Persisted. |
| `CODE_REMOVE` | `<decimal>` | `Gate: CODE_ACK:OK` / `CODE_ACK:NOT_FOUND` / `CODE_ACK:ERROR` | Removes a code from the list. Persisted. |
| `CODE_LIST` | none | `Gate: CODES:<code>,<code>,…` or `Gate: CODES:NONE` | Lists all registered codes as a single text frame (not a `CODE_ACK`). |
| `CODE_CLEAR` | none | `Gate: CODE_ACK:OK` | Empties the entire code list. Persisted. |

Unknown verbs are silently ignored (no NACK spam on the mesh).

### TRIGGERED event format

When a received RF code matches any registered entry, the firmware emits:

```
Gate: TRIGGERED:<decimal>
```

Example: `Gate: TRIGGERED:150910`. Downstream parsers can correlate the `<decimal>` against the list returned by `CODE_LIST` to identify which physical sensor fired.

### Examples

```
@ALL STATUS                    → Gate: STATUS: …
@Gate STATUS                   → Gate: STATUS: …
@Gate HB_OFF                   → Gate: HB_ACK:OK
@Gate HB_INTERVAL:5            → Gate: HB_ACK:OK
@Gate REBOOT                   → Gate: REBOOT_ACK:OK (then the Nano resets)
@Gate HITS_RESET               → Gate: HITS_RESET_ACK:OK
@Gate DEBOUNCE_SET:5           → Gate: DEBOUNCE_ACK:OK
@Gate CODE_LIST                → Gate: CODES:150910
@Gate CODE_ADD:4444222         → Gate: CODE_ACK:OK
@Gate CODE_ADD:150910          → Gate: CODE_ACK:EXISTS
@Gate CODE_REMOVE:4444222      → Gate: CODE_ACK:OK
@Gate CODE_REMOVE:404          → Gate: CODE_ACK:NOT_FOUND
@Gate CODE_CLEAR               → Gate: CODE_ACK:OK
@Other STATUS                  → (ignored)
```

## Firmware Logic

### setup()

1. Initialize USB serial at 115200 baud (debug)
2. Initialize SoftwareSerial at 9600 baud (Meshtastic)
3. Enable RCSwitch interrupt receiver on D2 (INT0)
4. Read `bootCount` from EEPROM, increment, write back
5. Load `hbEnabled` and `hbIntervalMin` from EEPROM (fall back to defaults on 0xFF / out-of-range)
6. Send the first STATUS frame

### loop()

1. **RF event handling:** When rc-switch receives a valid code, the 10 s debounce window is checked. If the code matches `CODE_OPEN`, `hitCount` is incremented and `Gate: TRIGGERED` is sent to the mesh and echoed on USB serial. `CODE_CLOSED` is handled the same way (when configured). Unrecognised codes are logged to USB serial as `RF unknown: <decimal>` and not forwarded.
2. **Inbound CMD handling:** `pollCmd()` drains the SoftwareSerial RX buffer into a line buffer. On `\n`, the line is dispatched to the verb handlers described in the [CMD Protocol](#cmd-protocol) section.
3. **STATUS heartbeat:** When `hbEnabled` is true and `hbIntervalMin * 60000` ms have elapsed since the last STATUS, send the STATUS frame on both the mesh UART and USB serial.

## Build and Upload

All commands use Make targets that wrap PlatformIO:

```bash
make build          # Compile firmware
make upload         # Flash to Nano via USB (auto-detects port)
make monitor        # Serial monitor at 115200 baud (Nano debug output)
make learn-sensor   # USB serial monitor tuned for discovering a new 433 MHz sensor code
make clean          # Clean build artifacts
```

Ensure the Nano is connected via USB. CH340 driver must be installed on the host.

## Debug Serial

The Nano's hardware UART (USB serial at 115200 baud) echoes all messages sent to Meshtastic plus unknown RF codes. Connect to the Nano's USB port and run `make monitor` to observe in real time.

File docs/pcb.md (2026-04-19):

# PCB Design Documentation

## Board Specifications

| Parameter | Value |
|---|---|
| Dimensions | 75 x 66 mm |
| Layers | 2 (F.Cu + B.Cu) |
| Material | FR-4 |
| Thickness | 1.6 mm |
| Surface finish | HASL (lead-free) |
| Min trace width | 0.25 mm (signal), 0.50 mm (power) |
| Min drill | 0.8 mm |
| Via size | 1.4 mm pad / 0.8 mm drill |
| Text minimum | 0.8 mm height, 0.15 mm stroke |
| Format | KiCad 10 (S-expression, version 20221018) |
| DRC status | 0 violations, 0 unconnected nets |

## Generation

The PCB file `pcb/gate_sensor_v2.kicad_pcb` is generated programmatically by `pcb/gate_sensor_pcb_v2.py`. This Python script writes KiCad S-expressions directly with no dependency on pcbnew or SWIG. It is compatible with KiCad 7-10.

To regenerate:
```bash
cd pcb && python3 gate_sensor_pcb_v2.py
```

## Board Outline

75x66mm rectangle with a USB-C notch at the top edge (X=10 to X=29, 8mm deep) for the Heltec's USB connector. Four M3 mounting holes at the corners (4mm inset).

```
         10    29
    ┌─────┘    └──────────────────────────┐
    │     USB-C notch                     │
    │                                     │  75mm
    │  U3 Heltec    U2 RXB6   U1 Nano    │
    │                                     │
    │  C2   J4-sw              J2-PWR    │
    └─────────────────────────────────────┘
                     75mm
```

## Component Placement

### Modules (top half of board)

| Ref | Component | Position | Footprint | Notes |
|-----|---|---|---|---|
| U3 | Heltec LoRa32 V3 | Left side, X=7-30, Y=10-53 | 2x18 pin socket, 22.86mm row spacing | Socketed, removable |
| U1 | Arduino Nano | Right side, X=55-70, Y=12-48 | 2x15 pin socket, 15.24mm row spacing | Socketed, removable |
| U2 | RXB6 433MHz | Center, X=44, Y=12-53 | 8-pin SIP, direct solder | Not removable |

### Passive Components (between modules)

| Ref | Component | Position | Notes |
|-----|---|---|---|
| R1 | 2.2k (logic divider series) | X=34-39, Y=24.7 | Horizontal, between RXB6 and Nano |
| R2 | 3.3k (logic divider shunt) | X=34, Y=25.8-29.8 | Vertical, below R1 junction |
| R5 | 10k (DE pull-up) | X=37.5-42.6, Y=47.6 | Horizontal, left of RXB6 pin 6 |
| C1 | 100nF ceramic (bypass) | X=38-40.5, Y=16 | Horizontal, near RXB6 VDD |
| C2 | 100uF electrolytic (bulk) | X=20, Y=59-61 | Vertical, below V5/GND buses |

### Connectors (bottom of board, Y=68)

| Ref | Component | Position | Notes |
|-----|---|---|---|
| J2 | PWR IN (screw terminal) | X=8, Y=68 | 5V + GND from Waveshare |
| J4 | PWR switch (JST-PH 2mm) | X=26, Y=68 | Toggle switch inline with 5V |

## Routing Strategy

### F.Cu (Front Copper) — Primary Layer

Used for all signal traces and most power traces:

- **Signal traces** (0.25mm): D3 to R1, HELTEC_RX from R1/R2 junction to GPIO47, HELTEC_TX direct from GPIO48 to Nano D4 (top-margin route with B.Cu vertical via at X=34 and B.Cu right-edge drop to R9), DE from R5 to RXB6
- **Power traces** (0.50mm): V5 bus (horizontal, Y=56), GND bus (horizontal, Y=58, 0.60mm wide), V5_IN from J2 to J4, 5V drops to modules
- **3V3**: Short bridge between Heltec R2 and R3 only

### B.Cu (Back Copper) — Secondary Layer

Used for GND drops and traces that must cross F.Cu signals:

- **GND drops**: Vertical traces from pad-level vias down to the GND bus. Offset 2+ mm from pad columns to avoid shorting to through-hole pad copper.
- **V5 feed from J4**: Via at X=34, B.Cu vertical to V5 bus (crosses GND bus underneath)
- **V5 to Nano**: B.Cu vertical at X=76.78 (avoids crossing R14 GND stub)
- **V5 to RXB6**: B.Cu vertical at X=50 (between GND drops)
- **D2/RF signal**: B.Cu from X=48 (avoids crossing D3 trace)

### GND Drop Strategy

Through-hole pads have copper on both layers. B.Cu GND drops are offset from pad columns to clear the 1.8mm pad diameter:

| Drop | Pad X | Offset X | Direction |
|---|---|---|---|
| Heltec L1 | 7.0 | 4.5 | Left |
| Heltec R1 | 29.86 | 32.5 | Right |
| Nano L4 | 55.0 | 52.5 | Left |
| Nano R14 | 72.78 | 79.0 | Right |
| R2 GND | 33.92 | 36.0 | Right |
| RXB6 pin 8 | 44.0 | 41.5 | Left |
| RXB6 pins 2-3 | 44.0 | 46.5 | Right |

### Copper Pour

GND fill zones on both F.Cu and B.Cu, following the board outline (including USB-C notch). Settings:
- Clearance: 0.30mm
- Min thickness: 0.25mm
- Thermal relief gap: 0.508mm
- Thermal bridge width: 0.508mm

## Bus Layout

```
  Y=8.7   ──── 3V3 bus (Heltec R2-R3 bridge only, not distributed) ────
  
  Y=56.0  ════ V5 power bus (F.Cu, 0.50mm) ════════════════════════════
  Y=58.0  ════ GND bus (F.Cu, 0.60mm) ═════════════════════════════════
```

The V5 and GND buses span from X=3 (left of Heltec) to X=85 (right of Nano), with vertical drops/feeds to all modules and connectors.

## Manufacturing

### JLCPCB Settings

| Parameter | Value |
|---|---|
| Layers | 2 |
| PCB Thickness | 1.6mm |
| Surface Finish | HASL (lead-free) |
| Copper Weight | 1 oz |
| Min Track/Space | 0.25mm / 0.30mm |
| Min Drill | 0.8mm |
| Board Outline | Edge.Cuts layer |
| Quantity | 5 (minimum order) |

### Gerber Export

```bash
make fab     # generates Gerbers + drill files in pcb/output/
```

This runs `make gerbers` and `make drill` via the KiCad 10 Docker image (`kicad/kicad:10.0`). Output files are placed in `pcb/output/` ready for upload to JLCPCB.

### Other Make Targets

```bash
make drc          # design rule check -> pcb/output/drc_report.json
make svg          # board SVG -> pcb/output/board.svg
make pdf          # board PDF -> pcb/output/board.pdf
make pcb-stats    # board statistics
make pcb-upgrade  # upgrade to KiCad 10 format
```

## Silkscreen

- Component outlines and reference designators on F.SilkS
- Pin labels for all module pins (moved to F.Fab where they overlap copper)
- Title block: "GATE SENSOR CARRIER v2.5 / 75x66mm 2L 1.6mm HASL"
- Connector polarity markings (+5V, GND)
- Switch symbol on J4
- Verbose circuit notes on F.Fab (not visible on assembled board)

## Version History

- **v2.0**: Initial 2-layer design
- **v2.2**: DRC fixes — removed VIN/5V short, B.Cu GND drops with offset vias, B.Cu D4 routing to fix D4/GND short, 3V3 bus rerouted, text minimums enforced, 22 vias for proper 2-layer routing
- **v2.3**: Removed battery-voltage monitoring, added 3D assembly view generator, R5 silkscreen label placed above the resistor body (was on F.Fab only in v2.2). 0 DRC violations, 34/34 netlist self-test checks pass.
- **v2.4**: Added bidirectional UART — Heltec GPIO48 (L14) → R6 (4.7k) → Nano D4 (R9). R6 series resistor protects the Nano from back-feed through its ESD clamp diodes when the Heltec is USB-powered alone (e.g. during flashing) and the 5V rail is off. HELTEC_TX routed on F.Cu east from L14 through the R14/R15 pad gap, B.Cu vertical at X=34 past the HELTEC_RX trace, F.Cu along the top margin at Y=8.7 to R6. D4 routed F.Cu along Y=8.7 then B.Cu right-edge drop to R9. 0 DRC violations, 40/40 netlist self-test checks pass.
- **v2.5**: R6 removed — bring-up with the Meshtastic Serial module (TEXTMSG mode) proved the 4.7k series resistor attenuated the 3.3V signal below the ATmega328P's V_IH threshold at 5V logic, so zero bytes reached D4 until R6 was shorted out. HELTEC_TX is now a direct trace from Heltec GPIO48 (L14) to Nano D4 (R9), taking the same corridor the v2.4 HELTEC_TX/D4 pair used, just without the bridge at Y=8.7. Net count dropped by one (D4 net merged into HELTEC_TX). 0 DRC violations.

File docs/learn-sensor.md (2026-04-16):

# Learning a New 433 MHz Door Sensor

The firmware needs the decimal code your 433 MHz door sensor transmits on open events. The `make learn-sensor` target helps you discover it without flashing a separate learning sketch — the production firmware already logs every decoded RF code to USB serial.

## How it works

`firmware/src/main.cpp` routes every RF hit through two paths:

- If the code matches `CODE_OPEN` (from `firmware/include/config.h`) → sends `Gate: TRIGGERED` over mesh **and** echoes the line on USB serial.
- Otherwise → prints `RF unknown: <decimal>` on USB serial only (not forwarded to mesh).

When you swap in a new sensor whose code doesn't match `CODE_OPEN`, every one of its transmissions surfaces as an `RF unknown:` line with the decimal value.

## Procedure

1. Flash the current firmware once: `make upload`.
2. Open the learning monitor: `make learn-sensor`. The target streams the Nano's USB serial at 115200 baud.
3. Trigger the sensor (open/close the door) several times. You'll see bursts like:

        RF unknown: 150910
        RF unknown: 150910
        RF unknown: 150910

   Common 433 MHz EV1527 / PT2260-style sensors retransmit the same code 4–10 times per trigger for reliability, so the same decimal should repeat. Ignore one-off values — those are RF noise or unrelated devices in range (weather stations, car remotes, etc.).

4. Once you've confirmed a stable decimal, copy it into `firmware/include/config.h`:

        #define CODE_OPEN    150910   // your learned value

5. Re-flash: `make upload`. From this point on the sensor fires `Gate: TRIGGERED` on the mesh instead of `RF unknown:` on USB.

## Notes

- **Many sensors emit the same code on open and close** (KERUI D026 does). `CODE_CLOSED` is defined in `config.h` but left at `0` (disabled) for this reason. If yours emits a distinct close code, set `CODE_CLOSED` to that value.
- `DEBOUNCE_MS` (10 s by default) collapses retransmit bursts into a single mesh event. During learning, the debounce doesn't affect USB output — every decoded code is printed.
- Press `Ctrl+C` (or `Ctrl+]` in `pio device monitor`) to exit the learning monitor.

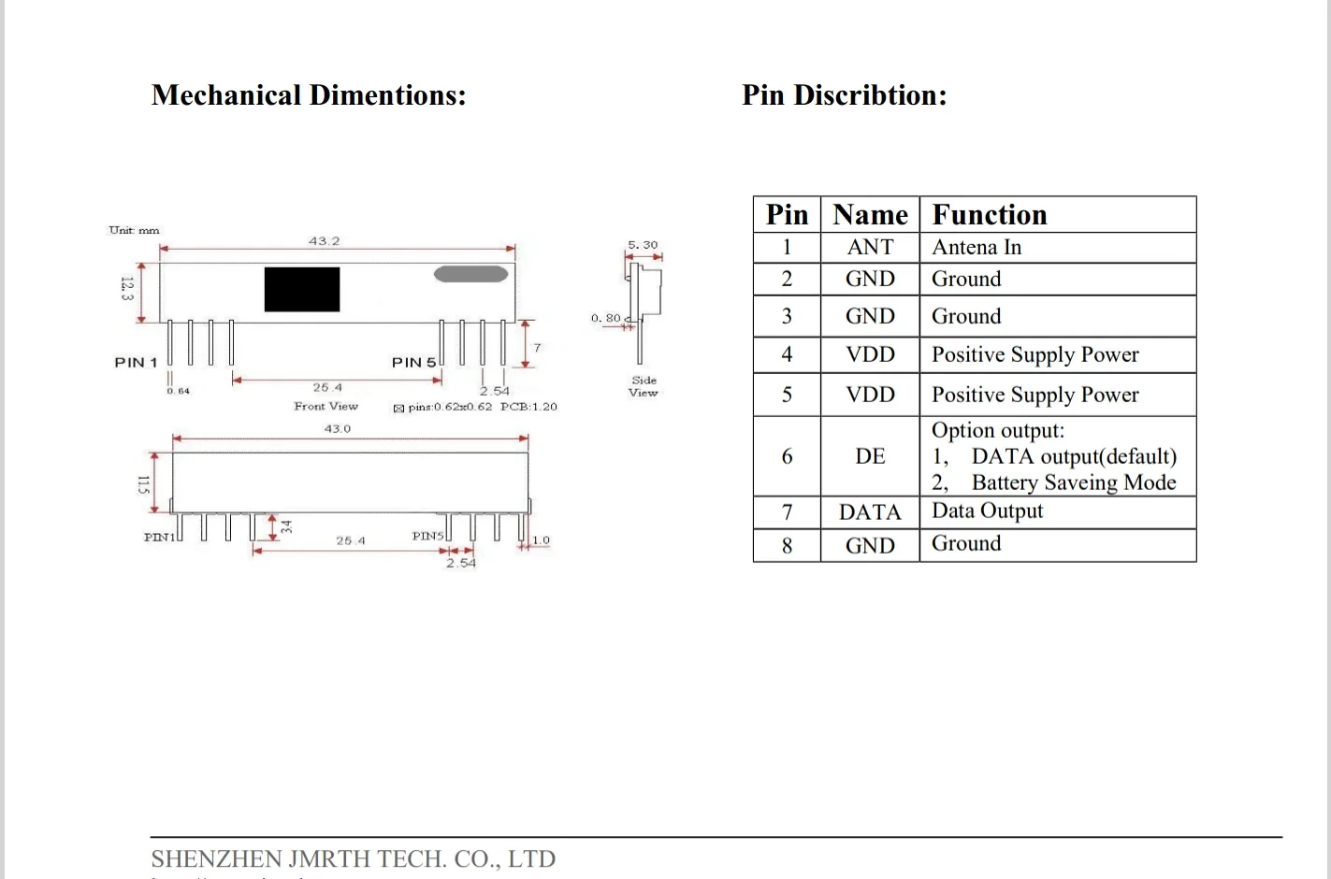
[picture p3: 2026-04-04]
pin-outs/rxb6.webp

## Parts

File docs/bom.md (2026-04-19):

# Bill of Materials (~$52 with solar · ~$36 bare)

## Core Components

| # | Component | Purpose | ~Price |
|---|---|---|---|
| 1 | Heltec WiFi LoRa 32 V3 | LoRa bridge (Meshtastic firmware) | $18 |
| 2 | Arduino Nano (CH340) | Sensor bridge MCU | $1.50 |
| 3 | RXB6 433MHz receiver (8-pin SIP) | RF signal input. 2 groups of 4 pins, 25.4mm gap. Direct solder to PCB. | $1 |
| 4 | KERUI D026 door sensor | 433MHz open/close sensor | $4 |
| 5 | Waveshare Solar Power Mgr D | Solar UPS, dual 18650 | $8 |
| 6 | 2x 18650 3000mAh | Battery backup (~57h) | $4 |
| 7 | 6V 2W solar panel | Charging source | $4 |
| 8 | IP65 junction box 150x100x70mm | Weatherproof enclosure | $3 |
| 9 | Carrier PCB v2.5 (5x from JLCPCB) | 75x66mm custom board | $1 ea |

## Passive Components

| Ref | Value | Type | Purpose |
|-----|---|---|---|
| R1 | 2.2k | 1/4W axial | Logic level divider — series resistor (D3 to HELTEC_RX) |
| R2 | 3.3k | 1/4W axial | Logic level divider — shunt to GND (produces 3.0V from 5V) |
| R5 | 10k | 1/4W axial | **Optional — do-not-populate.** DE pull-up for RXB6 pin 6. Most RXB6 batches have an internal bias on DE, so the pin floats high on its own and the receiver runs fine with R5 omitted. Populate only if your specific unit stays in standby without it. |
| C1 | 100nF | Ceramic disc/MLCC | Bypass capacitor near RXB6 VDD (high-frequency noise filter) |
| C2 | 100uF | Electrolytic radial (6.3mm dia) | Bulk capacitor on 5V bus (inrush/ripple smoothing) |

## Connectors and Hardware

| # | Component | Purpose |
|---|---|---|
| 1 | 2x18 female pin headers (2.54mm) | Heltec socket |
| 2 | 2x15 female pin headers (2.54mm, 15.24mm spacing) | Nano socket |
| 3 | 2-pin screw terminal (5.08mm) | J2 (PWR IN) |
| 4 | JST-PH 2mm 2-pin connector | J4 (power switch) |
| 5 | Toggle switch or JST-PH jumper | Inline power switch for J4 |
| 6 | SMA female bulkhead connector | 433MHz antenna feedthrough |
| 7 | PG7 cable gland | Weatherproof cable entry |
| 8 | 4x M3 standoffs + screws + nuts | PCB mounting (3.2mm holes) |

## Power Notes

- **Nano powered via 5V pin** (R12 on the socket), NOT via VIN. VIN has an onboard regulator that would cause a feedback loop if connected to the regulated 5V bus.
- **RXB6 powered from 5V** (pins 4 and 5), NOT 3.3V. The superheterodyne receiver has better sensitivity at 5V. The data output is still compatible with 5V logic on Nano D2.
- **Heltec powered via 5V** on L2. Its onboard regulator steps down to 3.3V internally.
- Total system draw: ~105mA from the Waveshare 5V output.

## Cost Summary

| Configuration | What's included | Approx. total |
|---|---|---|
| **With solar (self-contained, off-grid)** | All core, enclosure, passives, connectors + Waveshare Solar Mgr D ($8) + 2× 18650 ($4) + 6V 2W panel ($4) | **~$52** |
| **Bare (bring your own 5V)** | Everything above except the solar block — needs any 5V source on J2 | **~$36** |
| **With USB-C wall adapter** | Bare + a 5V/1A USB-C adapter (~$4) | **~$40** |

Numbers assume 2026 prices from AliExpress / LCSC in small quantities. Passives, headers, the screw terminal, JST-PH, SMA bulkhead, cable gland, and M3 mounts together come to ~$3.50; the core electronics (Heltec $18, Nano $1.50, RXB6 $1, KERUI D026 $4, PCB $1, IP65 box $3) total $28.50.

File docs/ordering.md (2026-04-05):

# JLCPCB Ordering Guide

## Generate Fabrication Files

```bash
make fab    # exports Gerbers + drill files to pcb/output/
```

Then zip the contents of `pcb/output/`:

```bash
cd pcb/output && zip -r ../../gate_sensor_gerbers.zip . && cd ../..
```

## Upload to JLCPCB

1. Go to https://www.jlcpcb.com and click **Order now**
2. Click **Add gerber file** and upload `gate_sensor_gerbers.zip`
3. JLCPCB auto-detects board dimensions (75 x 66 mm) and layer count (2)

## Order Form Settings

### Base Options

| Setting | Value | Notes |
|---|---|---|
| Base Material | FR-4 | Default, no change needed |
| Layers | 2 | Auto-detected |
| Dimensions | 75 x 66 mm | Auto-detected |
| PCB Qty | 5 | Minimum order. 5 and 10 are usually the same price. |
| Product Type | Industrial/Consumer electronics | Default |

### Board Specs

| Setting | Value | Notes |
|---|---|---|
| Different Design | 1 | Single design per panel |
| Delivery Format | Single PCB | Not panelized |
| PCB Thickness | 1.6 mm | Standard thickness, default |
| PCB Color | Green | Cheapest and fastest. Other colors may add 1-2 days. |
| Silkscreen | White | Default for green boards |
| Surface Finish | **LeadFree HASL-RoHS** | Select this instead of regular HASL |
| Outer Copper Weight | 1 oz | Default |
| Via Covering | Tented | Default, covers via holes with solder mask |

### High-Spec Options

| Setting | Value | Notes |
|---|---|---|
| Outer Copper Weight | 1 oz | Default. 2 oz not needed — max current is ~105mA. |
| Via Covering | Tented | Default. Covers via holes with solder mask on both sides. |
| Via Plating Method | Standard | Default. Electroless/electroplated copper. |
| Min via hole size/diameter | 0.3mm/0.5mm | Default. Our vias are 0.8mm drill / 1.4mm pad — well within limits. |
| Board Outline Tolerance | +/- 0.2mm | Default. |
| Confirm Production File | **Yes** | Recommended for first order. JLCPCB engineer reviews files before production. |
| Mark on PCB | **Remove Mark** | Prevents JLCPCB from placing their order number on the board. May cost ~$1 extra. Alternatively select "Specify a location" if you added a JLCJLCJLCJLC text placeholder. |
| Electrical Test | Flying Probe - Fully Test | Default. Tests all nets for shorts and opens. |
| Gold Fingers | No | Not used on this board. |
| Castellated Holes | No | Not used. |
| Edge Plating | No | Not used. |
| Blind Slots | No | Not used. Board has only standard through-hole slots. |
| UL Marking | No | Not required for prototype/hobby use. |

### Advanced Options

| Setting | Value | Notes |
|---|---|---|
| 4-Wire Kelvin Test | No | Default. Only needed for ultra-low-resistance measurements. |
| Paper between PCBs | No | Default. Boards are individually separated in the package. |
| Appearance Quality | IPC Class 2 | Default. Standard quality for commercial electronics. |
| Silkscreen Technology | Ink-jet Printing | Default. Sufficient for 0.8mm text and pin labels. |
| Package Box | Default | Standard JLCPCB packaging. |
| Inspection Report | No | Not needed for prototype orders. |
| PCB Remark | *(leave blank)* | Optional field for special instructions to the fab. Not needed. |

## Checkout

1. Review the auto-generated PCB preview — verify it matches your board outline and drill holes
2. Save to Cart
3. At checkout, select shipping (economy is usually fine for prototype boards)
4. Typical turnaround: 2-5 days production + shipping

## What You Receive

- 5x bare PCBs (no components soldered)
- All through-hole components must be hand-soldered — see [assembly.md](assembly.md)
- The boards arrive in a vacuum-sealed bag

## Reorder

For repeat orders, JLCPCB saves your Gerber files. You can reorder from your order history without re-uploading.

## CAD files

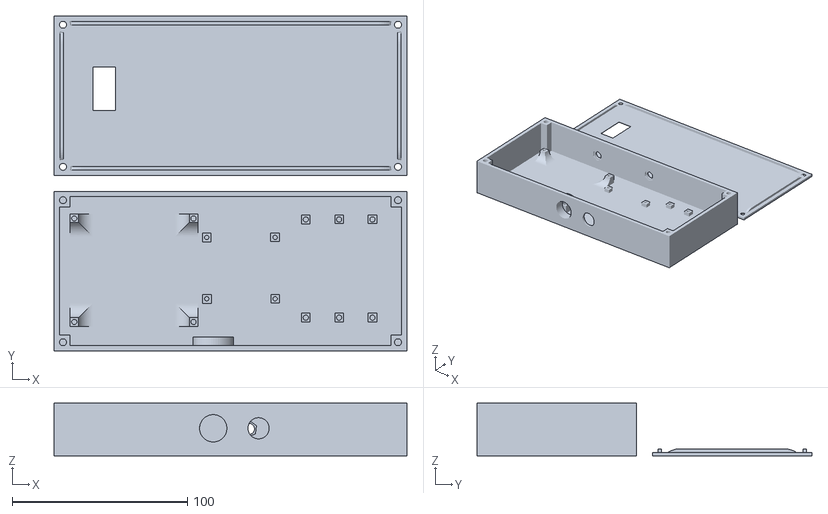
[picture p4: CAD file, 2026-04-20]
3dcase/gatesensor-v1.stl
201.0 x 191.0 x 30.0

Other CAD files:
3dcase/gatesensor-v1.f3d

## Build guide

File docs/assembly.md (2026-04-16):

# Assembly and Setup Guide

## Prerequisites

- Soldering iron with fine tip (for through-hole components)
- Solder (0.8mm rosin core recommended)
- Wire strippers and flush cutters
- Multimeter (for continuity checks)
- USB-A to Mini-B cable (for Arduino Nano)
- USB-C cable (for Heltec LoRa32 V3)
- Computer with PlatformIO installed

## Phase 1: PCB Assembly

### Soldering Order

Solder components in this order (smallest to largest, inside to outside):

1. **Passive components (R1, R2, R5, C1)**
   - R1 (2.2k) — horizontal, between Nano and RXB6 areas
   - R2 (3.3k) — vertical, below R1 junction
   - R5 (10k) — horizontal, left of RXB6 pin 6 area (DE pull-up)
   - C1 (100nF ceramic) — horizontal, near RXB6 VDD area

2. **C2 (100uF electrolytic)** — observe polarity (+) marked on silkscreen and capacitor stripe

3. **Pin headers for Heltec (U3)** — 2x18 female pin sockets. Solder from the back side. Use the Heltec module itself as an alignment jig (insert pins, flip, solder).

4. **Pin headers for Arduino Nano (U1)** — 2x15 female pin sockets, 15.24mm (600mil) row spacing. Same technique.

5. **RXB6 receiver (U2)** — direct solder, 8-pin SIP. This module is NOT socketed. Align pin 1 (ANT) to the board marking. The module body extends to the right of the pin column.

6. **Connectors**
   - J2 (PWR IN) — 2-pin screw terminal at bottom left. Pin 1 = +5V, Pin 2 = GND.
   - J4 (PWR SW) — JST-PH 2mm connector. Pin 1 = IN (from J2), Pin 2 = OUT (to 5V bus).

### Post-Solder Checks

Before inserting any modules, use a multimeter to verify:

1. **No shorts:** Check resistance between 5V and GND buses (should be high, not zero)
2. **Continuity:** Verify J2 pin1 to J4 pin1 (5V_IN path)
3. **Divider resistors:** Measure across R1+R2 (should read ~5.5k)
4. **Power switch:** With a jumper wire in J4, verify J2 pin1 reaches the 5V bus

## Phase 2: Learning the Sensor Code

The production firmware already logs every decoded 433 MHz code to USB serial, so no separate learning sketch is needed. The default `CODE_OPEN` in `firmware/include/config.h` is preloaded with the KERUI D026 value (`150910`) — skip this phase if you are using that exact sensor and it triggers correctly.

### Learning Procedure

1. **Flash the current firmware:**
   ```bash
   make upload
   ```

2. **Open the learning monitor:**
   ```bash
   make learn-sensor
   ```
   This streams the Nano's USB serial at 115200 baud.

3. **Trigger the sensor** (open/close the door) several times. Unknown codes appear as:
   ```
   RF unknown: 150910
   RF unknown: 150910
   RF unknown: 150910
   ```
   EV1527 / PT2260-style sensors retransmit the same code 4–10 times per trigger — ignore one-off values (noise, neighboring remotes).

4. **Update `firmware/include/config.h`:**
   ```c
   #define CODE_OPEN    150910   // your learned value
   ```
   KERUI D026 emits the same code on open and close, so `CODE_CLOSED` stays at `0` (disabled). If your sensor emits a distinct close code, set it there.

5. **Re-flash and verify:**
   ```bash
   make upload
   make monitor
   ```
   Trigger the sensor and confirm you see `Gate: TRIGGERED` lines (one per physical trigger — the 10 s debounce collapses each retransmit burst into a single mesh event).

See [learn-sensor.md](learn-sensor.md) for the full walkthrough.

## Phase 3: Meshtastic Flash & Configure

The Heltec LoRa32 V3 runs stock Meshtastic firmware with the serial module enabled. Both the firmware flash and the serial-module configuration are automated by `scripts/flash-heltec-meshtastic.sh`.

### Prerequisites

- Python tools: `pip install esptool meshtastic`
- GitHub CLI: `gh` (used to fetch the latest Meshtastic release)
- `.env` file at the project root with your 256-bit mesh PSK:
  ```bash
  cp .env.example .env
  # Edit .env and set MESH_PSK to a base64-encoded 256-bit key
  ```

### One-command Flash + Configure

Connect the Heltec via USB-C, put it in boot mode (hold BOOT, press and release RST, release BOOT), then run:

```bash
./scripts/flash-heltec-meshtastic.sh              # defaults: auto-detect port, EU_868, latest release
./scripts/flash-heltec-meshtastic.sh -r US        # US region
./scripts/flash-heltec-meshtastic.sh --help       # all options
```

The script downloads the latest stock Meshtastic release, erases flash, writes firmware + BLE OTA + LittleFS, then applies the full gate-sensor config and verifies every setting before closing.

### Settings Applied

| Setting | Value | Notes |
|---|---|---|
| `lora.region` | `EU_868` (configurable `-r`) | Select the region your mesh operates in |
| Channel PSK (index 0) | `$MESH_PSK` | 256-bit private-channel key from `.env` |
| `position.gps_mode` | `NOT_PRESENT` | Gate sensor has no GPS module |
| `telemetry.device_update_interval` | `1800` | Telemetry broadcast every 30 min |
| `serial.enabled` | `true` | Serial module on |
| `serial.echo` | `false` | Don't echo mesh text back out the UART |
| `serial.rxd` | `47` | GPIO47 (Heltec L13). NOT GPIO44 (conflicts with CP2102 USB-UART). |
| `serial.txd` | `48` | Parked on unused GPIO. NOT `0` — GPIO0 is the ESP32-S3 boot strap and silently kills RX. |
| `serial.baud` | `BAUD_9600` | Matches Nano SoftwareSerial (`MESH_BAUD`) |
| `serial.timeout` | `0` | Defaults |
| `serial.mode` | `TEXTMSG` | Each UART line arrives in the mesh as a chat message |
| Owner long / short | `GateSensor` / `GATE` | Human-readable node identity |
| `bluetooth.enabled` | `false` | Not used; saves power |

Separate invocations are available if you need them:

```bash
./scripts/flash-heltec-meshtastic.sh --flash-only       # write firmware, skip config
./scripts/flash-heltec-meshtastic.sh --config-only      # configure an already-flashed device
./scripts/flash-heltec-meshtastic.sh --confirm-config   # read back and verify without re-applying
```

### Verify Meshtastic

1. Insert the Heltec into the PCB socket
2. Power on via J4 switch
3. On another Meshtastic node on the same channel/PSK (phone app or second device), you should see the heartbeat: `GATE NODE: Online` every 5 minutes.

## Phase 4: Enclosure Assembly

### Components

- IP65 junction box 150x100x70mm
- SMA female bulkhead connector (for 433MHz antenna)
- PG7 cable gland (for solar panel cable)
- M3 standoffs, screws, and nuts (4 sets)
- 17.3cm wire antenna or external 433MHz antenna with SMA

### Assembly Steps

1. **Drill enclosure holes:**
   - SMA bulkhead hole on one side (typically 6.5mm)
   - PG7 cable gland hole on the bottom (12mm)
   - Optional: second PG7 for USB access during development

2. **Mount standoffs:** Install M3 standoffs inside the enclosure, matching the PCB's four corner mounting holes (4mm inset from edges).

3. **Install SMA connector:** Mount the SMA bulkhead connector. Connect a short wire from the SMA inner conductor to RXB6 pin 1 (ANT). Alternatively, solder a 17.3cm wire antenna directly to pin 1.

4. **Install cable gland:** Thread the solar panel and Waveshare power cables through the PG7 gland before connecting to J2.

5. **Mount PCB:** Secure the PCB to the standoffs with M3 screws.

6. **Wire power:**
   - Waveshare 5V OUT to J2 (observe polarity: pin 1 = +5V, pin 2 = GND)
   - Toggle switch between J4 pin 1 and pin 2 (or insert a JST-PH jumper)

7. **Insert modules:** Plug in the Heltec V3 and Arduino Nano into their sockets. The Heltec's USB-C connector should align with the board's USB-C notch.

8. **Seal:** Close the enclosure. Tighten the PG7 gland around the cable. Ensure the IP65 gasket is seated properly.

## Phase 5: Testing

### Bench Test (before enclosure)

1. Connect Waveshare Solar Power Manager D with batteries
2. Wire 5V and GND to J2
3. Insert jumper or switch on J4
4. Power on — Heltec should boot Meshtastic, Nano should send `GATE NODE: Online` heartbeat
5. Trigger the KERUI D026 sensor — each physical trigger should emit a single `Gate: TRIGGERED` message on the mesh (the 10 s debounce collapses the retransmit burst)

### Field Test

1. Mount the enclosure at the gate location
2. Position the solar panel for maximum sun exposure
3. Verify RF range: trigger the sensor at maximum expected distance
4. Monitor the mesh network for 24 hours:
   - `GATE NODE: Online` heartbeats every 5 minutes
   - `Gate: TRIGGERED` within a few seconds of each open/close

### Troubleshooting

| Symptom | Check |
|---|---|
| No heartbeat messages | Verify Meshtastic serial config (`serial.rxd=47`, `serial.txd=48`, `BAUD_9600`, `TEXTMSG`). Re-run `flash-heltec-meshtastic.sh --confirm-config`. Check 5V bus. |
| Gate events not detected | Verify `CODE_OPEN` in `firmware/include/config.h` matches your sensor — run `make learn-sensor` and check for `RF unknown: <decimal>` lines. Check RXB6 antenna. |
| Duplicate events per trigger | Confirm `DEBOUNCE_MS` is 10000 (10 s). Shorter values let the KERUI retransmit burst through as multiple events. |
| Messages garbled | Check logic level divider (R1/R2). Measure voltage at Heltec GPIO47 — should be ~3.0V when Nano TX is high. |
| No RF reception | Verify RXB6 is powered (5V on pins 4,5). Check DE pin pulled high (R5). Try shorter antenna distance. |
| Nano not booting | Verify power on Nano 5V pin (R12), not VIN. Check for solder bridges. Clone Nanos use optiboot — `platformio.ini` must be `board=nanoatmega328new` (115200 baud bootloader). |
| Meshtastic RX dead after config | If `serial.txd=0` got set, the ESP32-S3 UART init fails silently and also kills RX. Re-run the flash script to reset `txd=48`. |

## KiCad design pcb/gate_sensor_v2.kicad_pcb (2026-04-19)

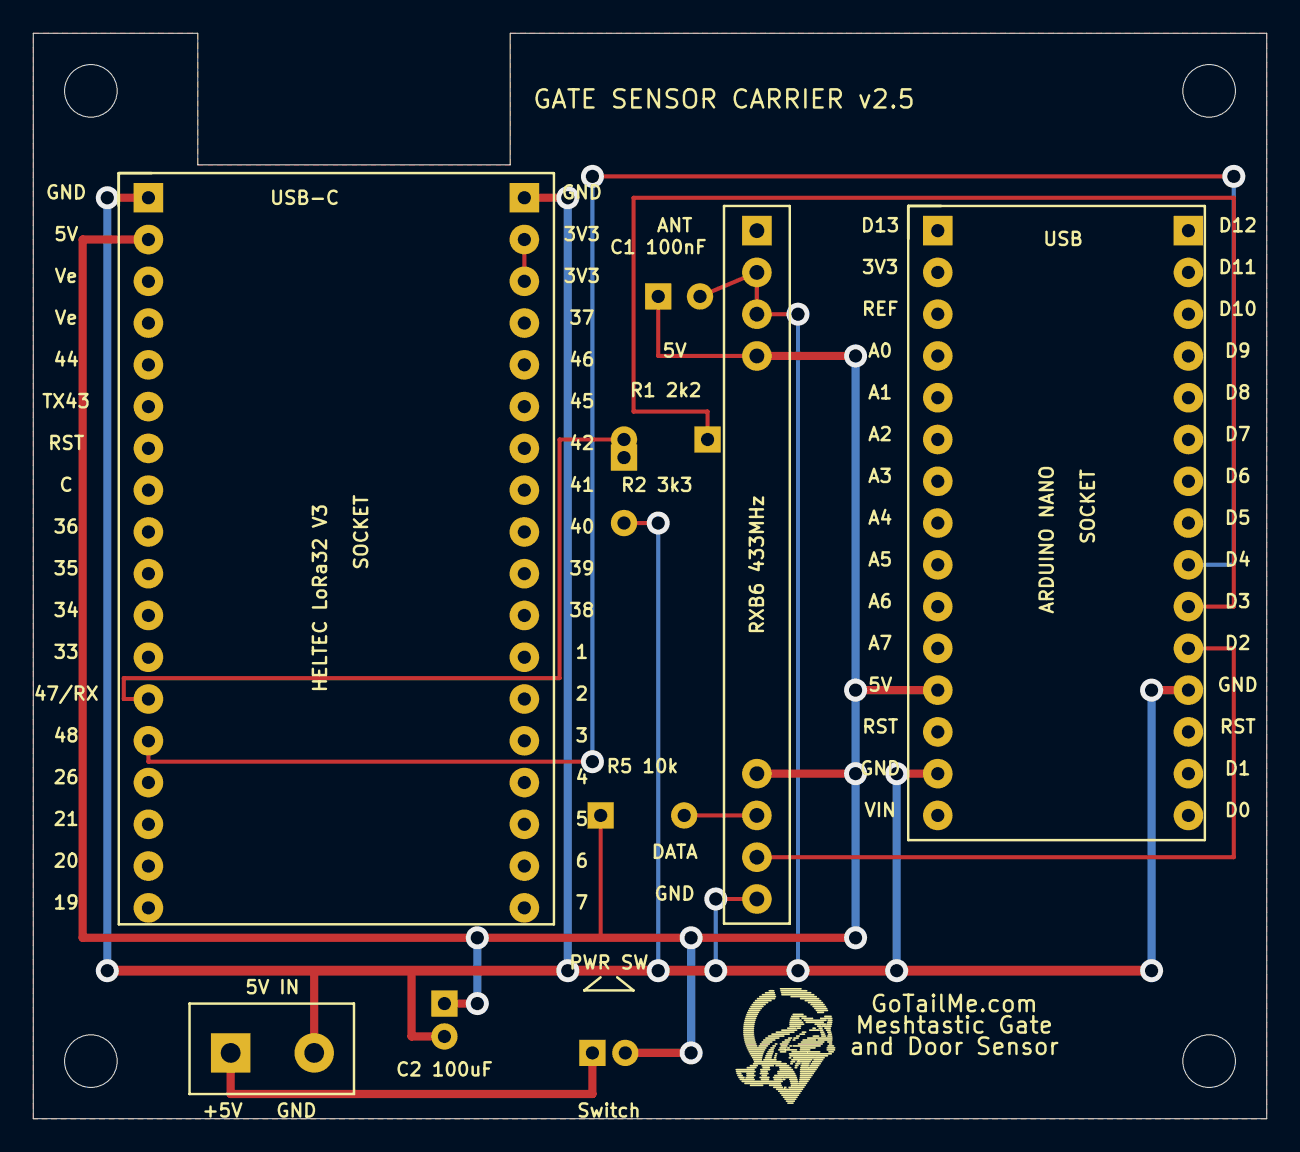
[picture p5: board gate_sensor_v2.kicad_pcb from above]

Board: 2 copper layers, 75.0 x 66.0 mm, 14 parts (0 on the bottom side), 9 nets.

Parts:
C1: 100nF; C1
C2: 100uF; C2
J2: PWR_IN_ScrewTerm; J2
J4: PWR_SW_JST_PH_2pin; J4
MH: M3_MountHole; MH
MH#2, MH#3, MH#4: M3_MountHole; MH
R1: 2.2k; R1
R2: 3.3k; R2
R5: 10k_PU; R5
U1: Arduino_Nano_Socket; U1
U2: RXB6_433MHz_DirectSolder; U2
U3: Heltec_LoRa32_V3; U3

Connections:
3V3: U3.R2, U3.R3
5V: C1.1, C2.1, J4.2, R5.1, U1.L12, U2.4, U2.5, U3.L2
5V_IN: J2.1, J4.1
D2: U1.R11, U2.7
D3: R1.1, U1.R10
DE: R5.2, U2.6
GND: C1.2, C2.2, J2.2, R2.2, U1.L14, U1.R12, U2.2, U2.3, U2.8, U3.L1, U3.R1
HELTEC_RX: R1.2, R2.1, U3.L13
HELTEC_TX: U1.R9, U3.L14

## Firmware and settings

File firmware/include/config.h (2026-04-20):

#ifndef CONFIG_H
#define CONFIG_H

// --- 433 MHz Sensor Codes ---
// Codes are a runtime-mutable list (up to MAX_CODES entries) stored in
// EEPROM and managed via CODE_ADD / CODE_REMOVE / CODE_LIST / CODE_CLEAR.
// On a fresh chip (all EEPROM slots 0xFFFFFFFF), the firmware seeds the
// list with DEFAULT_CODE_OPEN so out-of-the-box installs still detect the
// factory-calibrated sensor without any CMDs.
#define DEFAULT_CODE_OPEN 150910   // KERUI D026 open/close code (factory seed; 0 disables seeding)
#define MAX_CODES         16       // number of code slots (each 4 B in EEPROM)
#define CODE_NAME_LEN     16       // bytes per name slot (15 chars + '\0')

// Unknown RF codes at or above this value are broadcast as
// "TRIGGERED:<code> unknown" so operators can CODE_ADD them from the mesh.
// Codes below this are treated as 433 MHz noise and stay on USB debug only.
#define UNKNOWN_MIN_CODE  1000UL

// --- Sensor Identity ---
// SENSOR_NAME is the instance prefix used in every outbound mesh frame
// ("Gate: STATUS: ...", "Gate: TRIGGERED"). Mirrors AntiHunter's "AH34:" pattern
// so parsers that expect "<id>:" at the start of a STATUS frame work cleanly.
#define SENSOR_NAME "Gate"

// SENSOR_TYPE is the uppercase sensor-class identifier carried in the STATUS
// frame's Type: field. DigiNode CC uses this (not the prefix) to classify the
// node, so future sensor builds can swap "GATESENSOR" for "MOTION", "DOOR",
// "WINDOW", etc. without touching the dispatcher.
#define SENSOR_TYPE "GATESENSOR"

// --- Pin Assignments ---
#define RF_PIN      2   // RXB6 DATA -> Nano D2 (INT0 for RCSwitch)
#define SERIAL_TX   3   // Nano D3 -> 2.2k/3.3k divider -> Heltec GPIO47
#define SERIAL_RX   4   // Nano D4 <- direct trace <- Heltec GPIO48 (Meshtastic TX, PCB v2.5)

// --- Timing (milliseconds) ---
// STATUS frame is emitted on boot and every (hbIntervalMin * 60000) ms after.
// 30 min default keeps airtime low while still beating DigiNode CC's 16-min
// NodeOnlineTimeout. The interval is runtime-configurable via HB_INTERVAL
// (see CMD handlers in main.cpp) and persisted in EEPROM.
#define DEFAULT_HB_MIN       30   // default heartbeat interval (minutes)
#define HB_MIN_MIN            1   // minimum HB_INTERVAL value
#define HB_MIN_MAX           60   // maximum HB_INTERVAL value
#define DEFAULT_DEBOUNCE_SEC 10   // default RF debounce window (seconds)
#define DEBOUNCE_MIN_SEC      1   // minimum DEBOUNCE_SET value
#define DEBOUNCE_MAX_SEC     60   // maximum DEBOUNCE_SET value

// --- EEPROM Layout ---
// ATmega328P has 1 KB EEPROM. EEPROM reads as 0xFF when empty.
#define EEPROM_ADDR_BOOTCOUNT 0    // uint16_t (2 B)
#define EEPROM_ADDR_HB_EN     2    // uint8_t: 0=off, 1=on, 0xFF=default(on)
#define EEPROM_ADDR_HB_MIN    3    // uint8_t: heartbeat interval in minutes
#define EEPROM_ADDR_DEBOUNCE  4    // uint8_t: RF debounce seconds
// 5 reserved
#define EEPROM_ADDR_HITS      6    // uint32_t (4 B): cumulative hit counter, persisted
// 10-11 reserved
#define EEPROM_ADDR_CODES     12   // 16 × uint32_t (64 B): code list, 0xFFFFFFFF = empty slot
#define EEPROM_ADDR_NAMES     76   // 16 × CODE_NAME_LEN (256 B): parallel name table, 0xFF byte = empty

// --- CMD line parser ---
// CMDs arrive on SoftwareSerial RX (D4) from the Heltec's Meshtastic serial
// module. Format: @<target> <verb>[:<param>[:<param2>...]]
// target is ALL, Gate, or the SENSOR_NAME (case-insensitive).
#define CMD_BUF_SIZE          80  // max line length before forced reset

// --- UART Baud Rate ---
#define MESH_BAUD 9600  // Meshtastic serial module baud

// --- Meshtastic Serial Config ---
// Heltec V3 serial module must use GPIO47 for RX (not GPIO44, which
// conflicts with CP2102 USB-UART). Set via:
//   meshtastic --set serial.enabled true
//   meshtastic --set serial.rxd 47
//   meshtastic --set serial.baud BAUD_9600
//   meshtastic --set serial.mode TEXTMSG

#endif

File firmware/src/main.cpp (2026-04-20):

#include <Arduino.h>
#include <EEPROM.h>
#include <RCSwitch.h>
#include <SoftwareSerial.h>
#include <avr/wdt.h>
#include <ctype.h>
#include <string.h>
#include <stdlib.h>
#include "config.h"

RCSwitch rf = RCSwitch();
SoftwareSerial meshSerial(SERIAL_RX, SERIAL_TX);

unsigned long lastStatus = 0;
unsigned long lastUnknownEvent = 0;       // global rate-limit for unknown-code chatter
uint16_t bootCount = 0;
uint32_t hitCount = 0;                    // persisted in EEPROM

// Runtime config (loaded from EEPROM on boot, mutated by CMDs)
bool    hbEnabled     = true;
uint8_t hbIntervalMin = DEFAULT_HB_MIN;
uint8_t debounceSec   = DEFAULT_DEBOUNCE_SEC;

// Dynamic 433 MHz code list. Empty slot sentinel = 0xFFFFFFFF (fresh EEPROM).
uint32_t      codes[MAX_CODES];
char          codeNames[MAX_CODES][CODE_NAME_LEN];   // parallel; empty string = unnamed
unsigned long codeLastEvent[MAX_CODES];              // parallel; per-code debounce (RAM only)
uint8_t       codesCount = 0;
#define CODE_EMPTY 0xFFFFFFFFUL

// Inbound CMD line buffer
char    cmdBuf[CMD_BUF_SIZE];
uint8_t cmdLen = 0;

void sendMessage(const char* msg) {
    meshSerial.println(msg);
    Serial.println(msg);  // Debug echo
}

// Emits "Gate: TRIGGERED:<code> <name>". `name` may be NULL or ""; both render
// as "unnamed" so downstream parsers always see a two-token payload.
void sendTriggered(uint32_t code, const char* name) {
    char buf[96];
    snprintf(buf, sizeof(buf), "%s: TRIGGERED:%lu %s",
             SENSOR_NAME, (unsigned long)code,
             (name && name[0]) ? name : "unnamed");
    sendMessage(buf);
}

void sendStatus() {
    unsigned long upSec = millis() / 1000UL;
    unsigned int h = (unsigned int)(upSec / 3600UL);
    unsigned int m = (unsigned int)((upSec / 60UL) % 60UL);
    unsigned int s = (unsigned int)(upSec % 60UL);

    char buf[128];
    snprintf(buf, sizeof(buf),
        "%s: STATUS: Mode:ARMED Scan:GATE Hits:%lu Temp:0.0C "
        "Up:%02u:%02u:%02u Type:%s Boot:%u",
        SENSOR_NAME,
        (unsigned long)hitCount,
        h, m, s,
        SENSOR_TYPE,
        (unsigned)bootCount);
    sendMessage(buf);
}

// Uniform ACK emitter: "<SENSOR_NAME>: <VERB>_ACK:<status>"
void sendAck(const char* verb, const char* status) {
    char buf[64];
    snprintf(buf, sizeof(buf), "%s: %s_ACK:%s", SENSOR_NAME, verb, status);
    sendMessage(buf);
}

// ── EEPROM helpers ─────────────────────────────────────

void saveHitCount() {
    EEPROM.put(EEPROM_ADDR_HITS, hitCount);
}

void saveCodes() {
    for (uint8_t i = 0; i < MAX_CODES; i++) {
        EEPROM.put(EEPROM_ADDR_CODES + i * 4, codes[i]);
    }
}

// Writes only one name slot — callers changing a single name avoid rewriting
// the whole 256 B table, preserving EEPROM write cycles.
void saveNameSlot(uint8_t idx) {
    int base = EEPROM_ADDR_NAMES + (int)idx * CODE_NAME_LEN;
    for (uint8_t j = 0; j < CODE_NAME_LEN; j++) {
        EEPROM.update(base + j, (uint8_t)codeNames[idx][j]);
    }
}

void saveNames() {
    for (uint8_t i = 0; i < MAX_CODES; i++) saveNameSlot(i);
}

void loadCodes() {
    codesCount = 0;
    for (uint8_t i = 0; i < MAX_CODES; i++) {
        EEPROM.get(EEPROM_ADDR_CODES + i * 4, codes[i]);
        if (codes[i] != CODE_EMPTY) codesCount++;

        // Read the parallel name slot. Fresh EEPROM is 0xFF, which is neither
        // a valid ASCII char nor a NUL — detect that and normalise to "".
        int base = EEPROM_ADDR_NAMES + (int)i * CODE_NAME_LEN;
        uint8_t first = EEPROM.read(base);
        if (first == 0xFF || first == 0x00) {
            codeNames[i][0] = '\0';
        } else {
            for (uint8_t j = 0; j < CODE_NAME_LEN; j++) {
                codeNames[i][j] = (char)EEPROM.read(base + j);
            }
            codeNames[i][CODE_NAME_LEN - 1] = '\0';  // force-terminate
        }
    }
    // Seed fresh chip with the factory-calibrated code so out-of-the-box
    // installs still work without a CODE_ADD from the operator.
    if (codesCount == 0 && DEFAULT_CODE_OPEN != 0) {
        codes[0] = DEFAULT_CODE_OPEN;
        codeNames[0][0] = '\0';
        codesCount = 1;
        saveCodes();
        saveNameSlot(0);
    }
}

// ── Code-list operations ──────────────────────────────

// Returns slot index of `c`, or -1 if not in the registry.
int8_t codeIndexOf(uint32_t c) {
    for (uint8_t i = 0; i < MAX_CODES; i++) {
        if (codes[i] == c) return (int8_t)i;
    }
    return -1;
}

bool codeKnown(uint32_t c) {
    return codeIndexOf(c) >= 0;
}

const char* codeNameFor(uint32_t c) {
    int8_t i = codeIndexOf(c);
    return (i >= 0) ? codeNames[i] : "";
}

// Valid name: NULL / "" (unnamed), or ≤15 chars of [A-Za-z0-9_-].
// Reject ':', space, '@' because those are CMD-format delimiters.
static bool nameValid(const char* s) {
    if (!s) return true;
    size_t n = strlen(s);
    if (n == 0) return true;
    if (n >= CODE_NAME_LEN) return false;
    for (size_t i = 0; i < n; i++) {
        char ch = s[i];
        if (!(isalnum((unsigned char)ch) || ch == '_' || ch == '-')) return false;
    }
    return true;
}

enum CodeAddResult { CODE_ADDED, CODE_UPDATED, CODE_EXISTS, CODE_FULL };

// Add `c` with `name` (NULL or "" means unnamed). If `c` already exists and
// a non-empty `name` differs from the stored name, overwrite → CODE_UPDATED.
// Same name (or no name supplied) on an existing code → CODE_EXISTS.
CodeAddResult codeAddOrUpdate(uint32_t c, const char* name) {
    for (uint8_t i = 0; i < MAX_CODES; i++) {
        if (codes[i] == c) {
            if (name && name[0] && strncmp(codeNames[i], name, CODE_NAME_LEN) != 0) {
                strncpy(codeNames[i], name, CODE_NAME_LEN - 1);
                codeNames[i][CODE_NAME_LEN - 1] = '\0';
                saveNameSlot(i);
                return CODE_UPDATED;
            }
            return CODE_EXISTS;
        }
    }
    for (uint8_t i = 0; i < MAX_CODES; i++) {
        if (codes[i] == CODE_EMPTY) {
            codes[i] = c;
            if (name && name[0]) {
                strncpy(codeNames[i], name, CODE_NAME_LEN - 1);
                codeNames[i][CODE_NAME_LEN - 1] = '\0';
            } else {
                codeNames[i][0] = '\0';
            }
            codeLastEvent[i] = 0;  // fresh slot fires on first RF match
            codesCount++;
            saveCodes();
            saveNameSlot(i);
            return CODE_ADDED;
        }
    }
    return CODE_FULL;
}

bool codeRemove(uint32_t c) {
    for (uint8_t i = 0; i < MAX_CODES; i++) {
        if (codes[i] == c) {
            codes[i] = CODE_EMPTY;
            codeNames[i][0] = '\0';
            codeLastEvent[i] = 0;
            if (codesCount > 0) codesCount--;
            saveCodes();
            saveNameSlot(i);
            return true;
        }
    }
    return false;
}

void codeClearAll() {
    for (uint8_t i = 0; i < MAX_CODES; i++) {
        codes[i] = CODE_EMPTY;
        codeNames[i][0] = '\0';
        codeLastEvent[i] = 0;
    }
    codesCount = 0;
    saveCodes();
    saveNames();
}

void sendCodeList() {
    // 16 slots × (8-digit code + '=' + 15-char name) + 15 commas + prefix ≈ 420 B.
    // Budget 256 to stay well under a LoRa payload; truncate with tail margin.
    char buf[256];
    int off = snprintf(buf, sizeof(buf), "%s: CODES:", SENSOR_NAME);
    if (codesCount == 0) {
        snprintf(buf + off, sizeof(buf) - off, "NONE");
    } else {
        bool first = true;
        for (uint8_t i = 0; i < MAX_CODES; i++) {
            if (codes[i] == CODE_EMPTY) continue;
            if (off >= (int)(sizeof(buf) - (CODE_NAME_LEN + 16))) break;  // tail margin
            const char* nm = codeNames[i][0] ? codeNames[i] : "unnamed";
            off += snprintf(buf + off, sizeof(buf) - off, "%s%lu=%s",
                            first ? "" : ",", (unsigned long)codes[i], nm);
            first = false;
        }
    }
    sendMessage(buf);
}

// ── REBOOT via watchdog ───────────────────────────────

static void doReboot() {
    sendAck("REBOOT", "OK");
    meshSerial.flush();
    Serial.flush();
    delay(100);                 // let UART bytes clear
    wdt_enable(WDTO_15MS);
    while (1) {}
}

// ── CMD parser ────────────────────────────────────────

static bool targetMatches(const char* target) {
    if (strcasecmp(target, "ALL") == 0) return true;
    if (strcasecmp(target, SENSOR_NAME) == 0) return true;
    return false;
}

static void handleCommand(const char* target, const char* verb, const char* param) {
    if (!targetMatches(target)) return;

    // STATUS: no ACK, the STATUS frame itself is the reply.
    if (strcasecmp(verb, "STATUS") == 0) {
        sendStatus();
        return;
    }

    // Heartbeat control
    if (strcasecmp(verb, "HB_ON") == 0) {
        hbEnabled = true;
        EEPROM.update(EEPROM_ADDR_HB_EN, 1);
        lastStatus = millis();
        sendAck("HB", "OK");
        return;
    }
    if (strcasecmp(verb, "HB_OFF") == 0) {
        hbEnabled = false;
        EEPROM.update(EEPROM_ADDR_HB_EN, 0);
        sendAck("HB", "OK");
        return;
    }
    if (strcasecmp(verb, "HB_INTERVAL") == 0) {
        if (param == NULL || *param == '\0') { sendAck("HB", "ERROR"); return; }
        int m = atoi(param);
        if (m < HB_MIN_MIN || m > HB_MIN_MAX) { sendAck("HB", "ERROR"); return; }
        hbIntervalMin = (uint8_t)m;
        EEPROM.update(EEPROM_ADDR_HB_MIN, hbIntervalMin);
        lastStatus = millis();
        sendAck("HB", "OK");
        return;
    }

    // System control
    if (strcasecmp(verb, "REBOOT") == 0) {
        doReboot();  // does not return
        return;
    }

    // Gate-specific
    if (strcasecmp(verb, "HITS_RESET") == 0) {
        hitCount = 0;
        saveHitCount();
        sendAck("HITS_RESET", "OK");
        return;
    }
    if (strcasecmp(verb, "DEBOUNCE_SET") == 0) {
        if (param == NULL || *param == '\0') { sendAck("DEBOUNCE", "ERROR"); return; }
        int s = atoi(param);
        if (s < DEBOUNCE_MIN_SEC || s > DEBOUNCE_MAX_SEC) { sendAck("DEBOUNCE", "ERROR"); return; }
        debounceSec = (uint8_t)s;
        EEPROM.update(EEPROM_ADDR_DEBOUNCE, debounceSec);
        sendAck("DEBOUNCE", "OK");
        return;
    }

    // RF code registry
    // Format: CODE_ADD:<code>[:<name>]
    // Re-issuing with a different name on an existing code updates the name.
    if (strcasecmp(verb, "CODE_ADD") == 0) {
        if (param == NULL || *param == '\0') { sendAck("CODE", "ERROR"); return; }
        char* endp = NULL;
        unsigned long c = strtoul(param, &endp, 10);
        if (c == 0UL || c > 0xFFFFFFUL) { sendAck("CODE", "ERROR"); return; }
        const char* name = NULL;
        if (endp && *endp == ':') {
            name = endp + 1;
            if (*name == '\0') name = NULL;   // trailing colon = no name
        } else if (endp && *endp != '\0') {
            sendAck("CODE", "ERROR");          // garbage after the number
            return;
        }
        if (!nameValid(name)) { sendAck("CODE", "ERROR"); return; }
        switch (codeAddOrUpdate((uint32_t)c, name)) {
            case CODE_ADDED:   sendAck("CODE", "OK");      break;
            case CODE_UPDATED: sendAck("CODE", "UPDATED"); break;
            case CODE_EXISTS:  sendAck("CODE", "EXISTS");  break;
            case CODE_FULL:    sendAck("CODE", "FULL");    break;
        }
        return;
    }
    if (strcasecmp(verb, "CODE_REMOVE") == 0) {
        if (param == NULL || *param == '\0') { sendAck("CODE", "ERROR"); return; }
        unsigned long c = strtoul(param, NULL, 10);
        sendAck("CODE", codeRemove((uint32_t)c) ? "OK" : "NOT_FOUND");
        return;
    }
    if (strcasecmp(verb, "CODE_LIST") == 0) {
        sendCodeList();
        return;
    }
    if (strcasecmp(verb, "CODE_CLEAR") == 0) {
        codeClearAll();
        sendAck("CODE", "OK");
        return;
    }
    // Unknown verb — silent ignore.
}

// Parses "@<target> <verb>[:<param>[:...]]". Mutates line in place.
// Meshtastic's Serial module in TEXTMSG mode prefixes received broadcasts with
// "<sender-shortname>: " (e.g. "1e44: @GATE HB_OFF"). Skip past an optional
// "<anything>: " prefix before looking for the '@' addressing token.
static void processCmdLine(char* line) {
    char* at = strchr(line, '@');
    if (!at) return;
    line = at;
    char* space = strchr(line + 1, ' ');
    if (!space) return;
    *space = '\0';
    const char* target = line + 1;
    char* rest = space + 1;
    while (*rest == ' ') rest++;

    char* colon = strchr(rest, ':');
    const char* param = NULL;
    if (colon) {
        *colon = '\0';
        param = colon + 1;
    }
    const char* verb = rest;
    if (*verb == '\0') return;
    handleCommand(target, verb, param);
}

void pollCmd() {
    while (meshSerial.available()) {
        int c = meshSerial.read();
        if (c < 0) break;
        if (c == '\r') continue;
        if (c == '\n') {
            if (cmdLen > 0) {
                cmdBuf[cmdLen] = '\0';
                processCmdLine(cmdBuf);
                cmdLen = 0;
            }
            continue;
        }
        if (cmdLen < CMD_BUF_SIZE - 1) {
            cmdBuf[cmdLen++] = (char)c;
        } else {
            cmdLen = 0;  // overflow — discard to avoid misparsing a truncation
        }
    }
}

// ── setup / loop ──────────────────────────────────────

void setup() {
    // Optiboot leaves the WDT enabled with its last value after a watchdog
    // reset, which would cause an immediate second reset if not cleared.
    wdt_disable();

    Serial.begin(115200);
    meshSerial.begin(MESH_BAUD);
    rf.enableReceive(digitalPinToInterrupt(RF_PIN));

    EEPROM.get(EEPROM_ADDR_BOOTCOUNT, bootCount);
    if (bootCount == 0xFFFF) bootCount = 0;
    bootCount++;
    EEPROM.put(EEPROM_ADDR_BOOTCOUNT, bootCount);

    // Heartbeat config
    uint8_t hbEn  = EEPROM.read(EEPROM_ADDR_HB_EN);
    uint8_t hbMin = EEPROM.read(EEPROM_ADDR_HB_MIN);
    hbEnabled = (hbEn == 0xFF) ? true : (hbEn != 0);
    if (hbMin == 0xFF || hbMin < HB_MIN_MIN || hbMin > HB_MIN_MAX) {
        hbIntervalMin = DEFAULT_HB_MIN;
    } else {
        hbIntervalMin = hbMin;
    }

    // Debounce config
    uint8_t dbs = EEPROM.read(EEPROM_ADDR_DEBOUNCE);
    if (dbs == 0xFF || dbs < DEBOUNCE_MIN_SEC || dbs > DEBOUNCE_MAX_SEC) {
        debounceSec = DEFAULT_DEBOUNCE_SEC;
    } else {
        debounceSec = dbs;
    }

    // Hit counter (fresh chip reads 0xFFFFFFFF → treat as 0)
    EEPROM.get(EEPROM_ADDR_HITS, hitCount);
    if (hitCount == 0xFFFFFFFFUL) hitCount = 0;

    // Code registry
    loadCodes();

    // Heltec ESP32 + Meshtastic needs several seconds to boot and open its
    // Serial module; sending STATUS earlier drops the frame into a dead UART.
    delay(8000);

    sendStatus();
    lastStatus = millis();
}

void loop() {
    unsigned long now = millis();

    // RF event handling — debounce is per-code, so two different codes fired
    // back-to-back both get reported. Unknown codes share one global window
    // to keep 433 MHz noise from flooding the mesh.
    if (rf.available()) {
        unsigned long code = rf.getReceivedValue();
        rf.resetAvailable();

        unsigned long debounceMs = (unsigned long)debounceSec * 1000UL;
        if (code != 0) {
            int8_t idx = codeIndexOf((uint32_t)code);
            if (idx >= 0) {
                if ((now - codeLastEvent[idx]) > debounceMs) {
                    codeLastEvent[idx] = now;
                    hitCount++;
                    saveHitCount();
                    sendTriggered((uint32_t)code, codeNames[idx]);
                }
            } else if ((now - lastUnknownEvent) > debounceMs) {
                lastUnknownEvent = now;
                // Unknown code — always log on USB for `make learn-sensor`.
                char buf[64];
                snprintf(buf, sizeof(buf), "RF unknown: %lu", code);
                Serial.println(buf);
                // Broadcast only if above the noise floor (short bursts at
                // 1-3 digits are 433 MHz chatter, not a real transmitter).
                if (code >= UNKNOWN_MIN_CODE) {
                    sendTriggered((uint32_t)code, "unknown");
                }
            }
        }
    }

    // Inbound CMD handling (Heltec GPIO48 → R6 → D4)
    pollCmd();

    // Periodic STATUS heartbeat (interval configurable via HB_INTERVAL)
    if (hbEnabled && (now - lastStatus >= (unsigned long)hbIntervalMin * 60000UL)) {
        lastStatus = now;
        sendStatus();
    }
}

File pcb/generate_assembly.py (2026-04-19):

#!/usr/bin/env python3
"""
Post-processor: adds 3D model references to gate_sensor_v2.kicad_pcb
Outputs gate_sensor_v2_assembly.kicad_pcb for 3D viewing in KiCad.

Usage:
  python3 generate_assembly.py          # generates assembly PCB
  make assembly                         # generates + exports STEP via AppImage
"""

import os, re, sys

SCRIPT_DIR = os.path.dirname(os.path.abspath(__file__))
INPUT  = os.path.join(SCRIPT_DIR, "gate_sensor_v2.kicad_pcb")
OUTPUT = os.path.join(SCRIPT_DIR, "gate_sensor_v2_assembly.kicad_pcb")

# KiCad 3D model base path variable (KiCad 10 resolves KICAD8 vars)
M = "${KICAD8_3DMODEL_DIR}"

# ── 3D model definitions per footprint reference ────────────────────
# Each entry: list of (model_path, offset_xyz, rotation_xyz)
# Offsets are relative to footprint center, in mm.
# Calculated from pad positions in gate_sensor_pcb_v2.py.

P = 2.54  # pin pitch

# Footprint centers (from generator):
# U3: cx=18.43, cy=31.59   U1: cx=62.62, cy=29.78   U2: cx=49.0, cy=32.32
#
# NOTE: KiCad 3D model offset Y is INVERTED from PCB Y.
# PCB Y increases downward, but model offset Y increases upward (3D convention).
# So: model_offset_y = -local_pcb_y

MODELS = {
    # ── U3: Heltec LoRa32 V3 — 2x pin socket 1x18 ──
    "U3": [
        # Left row socket: pin L1 at PCB local (-11.43, -21.59) → offset Y = +21.59
        (f"{M}/Connector_PinSocket_2.54mm.3dshapes/PinSocket_1x18_P2.54mm_Vertical.step",
         (-11.43, 21.59, 0), (0, 0, 0)),
        # Right row socket: pin R1 at PCB local (11.43, -21.59) → offset Y = +21.59
        (f"{M}/Connector_PinSocket_2.54mm.3dshapes/PinSocket_1x18_P2.54mm_Vertical.step",
         (11.43, 21.59, 0), (0, 0, 0)),
    ],

    # ── U1: Arduino Nano — 2x pin socket 1x15 ──
    "U1": [
        # Left row socket: pin L1 at PCB local (-7.62, -17.78) → offset Y = +17.78
        (f"{M}/Connector_PinSocket_2.54mm.3dshapes/PinSocket_1x15_P2.54mm_Vertical.step",
         (-7.62, 17.78, 0), (0, 0, 0)),
        # Right row socket: pin R1 at PCB local (7.62, -17.78) → offset Y = +17.78
        (f"{M}/Connector_PinSocket_2.54mm.3dshapes/PinSocket_1x15_P2.54mm_Vertical.step",
         (7.62, 17.78, 0), (0, 0, 0)),
    ],

    # ── U2: RXB6 433MHz — 2x pin socket 1x04 (female socket) ──
    "U2": [
        # Group 1 (pins 1-4): pin1 at PCB local (-5.0, -20.32) → offset Y = +20.32
        (f"{M}/Connector_PinSocket_2.54mm.3dshapes/PinSocket_1x04_P2.54mm_Vertical.step",
         (-5.0, 20.32, 0), (0, 0, 0)),
        # Group 2 (pins 5-8): pin5 at PCB local (-5.0, 12.70) → offset Y = -12.70
        (f"{M}/Connector_PinSocket_2.54mm.3dshapes/PinSocket_1x04_P2.54mm_Vertical.step",
         (-5.0, -12.70, 0), (0, 0, 0)),
    ],

    # ── Resistors (axial THT, 5.08mm pitch) ──
    # R1 (2.2k): horizontal, pad1(+X)=D3, pad2(-X)=HLTC_RX
    "R1": [
        (f"{M}/Resistor_THT.3dshapes/R_Axial_DIN0204_L3.6mm_D1.6mm_P5.08mm_Horizontal.step",
         (2.54, 0, 0), (0, 0, 180)),
    ],
    # R2 (3.3k): vertical (along PCB Y), use horizontal model + 90° Z rotation
    "R2": [
        (f"{M}/Resistor_THT.3dshapes/R_Axial_DIN0204_L3.6mm_D1.6mm_P5.08mm_Horizontal.step",
         (0, 1.99, 0), (0, 0, 90)),
    ],
    # R5 (10k): horizontal, pad1(-X)=V5, pad2(+X)=DE
    "R5": [
        (f"{M}/Resistor_THT.3dshapes/R_Axial_DIN0204_L3.6mm_D1.6mm_P5.08mm_Horizontal.step",
         (-2.54, 0, 0), (0, 0, 0)),
    ],
    # R6 removed in v2.5 — GPIO48 -> D4 is a direct trace.

    # ── Capacitors ──
    # C1 (100nF): ceramic disc, 2.54mm pitch
    "C1": [
        (f"{M}/Capacitor_THT.3dshapes/C_Disc_D3.0mm_W1.6mm_P2.50mm.step",
         (-1.27, 0, 0), (0, 0, 0)),
    ],
    # C2 (100uF): electrolytic radial, center at (20, 60), pads along Y → rotate -90°
    # Offset Y decreased to shift model down toward pads
    "C2": [
        (f"{M}/Capacitor_THT.3dshapes/CP_Radial_D5.0mm_P2.00mm.step",
         (0, 0, 0), (0, 0, -90)),
    ],

    # ── Connectors ──
    # J2 (SOLAR IN): screw terminal 5.08mm pitch, center at (14.54, 62.0)
    # pad1 at local (-2.54, 0)
    "J2": [
        (f"{M}/TerminalBlock_Phoenix.3dshapes/TerminalBlock_Phoenix_MKDS-1,5-2-5.08_1x02_P5.08mm_Horizontal.step",
         (-2.54, 0, 0), (0, 0, 0)),
    ],
    # J4 (PWR_SW): JST PH 2-pin, center at (27.0, 62.0)
    # 180° Z rotation so notch faces board edge, offset flipped to match
    "J4": [
        (f"{M}/Connector_JST.3dshapes/JST_PH_B2B-PH-K_1x02_P2.00mm_Vertical.step",
         (1.0, 0, 0), (0, 0, 180)),
    ],
}


def model_sexpr(path, offset, rotation):
    """Generate KiCad S-expression for a 3D model entry."""
    ox, oy, oz = offset
    rx, ry, rz = rotation
    return (
        f'    (model "{path}"\n'
        f'      (offset (xyz {ox:.4f} {oy:.4f} {oz:.4f}))\n'
        f'      (scale (xyz 1 1 1))\n'
        f'      (rotate (xyz {rx:.4f} {ry:.4f} {rz:.4f}))\n'
        f'    )'
    )


def find_footprint_blocks(text):
    """Find all footprint blocks and their reference names.
    Returns list of (ref_name, start_idx, end_idx) where end_idx
    points to the closing ')' of the footprint block."""
    blocks = []
    i = 0
    while i < len(text):
        # Find '(footprint "'
        match = re.search(r'\(footprint\s+"([^"]+)"', text[i:])
        if not match:
            break
        start = i + match.start()
        ref = match.group(1)

        # Find matching closing paren
        depth = 0
        j = start
        while j < len(text):
            if text[j] == '(':
                depth += 1
            elif text[j] == ')':
                depth -= 1
                if depth == 0:
                    blocks.append((ref, start, j))
                    break
            j += 1
        i = j + 1
    return blocks


def main():
    if not os.path.exists(INPUT):
        print(f"Error: {INPUT} not found. Run gate_sensor_pcb_v2.py first.")
        sys.exit(1)

    with open(INPUT, 'r') as f:
        text = f.read()

    # Process footprints in reverse order so indices stay valid
    blocks = find_footprint_blocks(text)
    blocks.reverse()

    added = 0
    for ref, start, end in blocks:
        if ref in MODELS:
            model_entries = "\n".join(
                model_sexpr(path, offset, rot)
                for path, offset, rot in MODELS[ref]
            )
            # Insert model entries before the closing ')' of the footprint
            text = text[:end] + "\n" + model_entries + "\n  " + text[end:]
            added += len(MODELS[ref])

    # Also skip MH (mount holes) — no model needed

    with open(OUTPUT, 'w') as f:
        f.write(text)

    print(f"""
Assembly PCB generated — {added} 3D models added
Output: {OUTPUT}
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

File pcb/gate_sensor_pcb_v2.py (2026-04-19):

#!/usr/bin/env python3
"""
Gate Sensor Carrier PCB v2.5 — KiCad S-expression generator
Writes gate_sensor_v2.kicad_pcb directly — NO pcbnew / SWIG dependency.
Compatible with KiCad 7–10.  Runs inside or outside KiCad.

v2.5: R6 removed — GPIO48 -> Nano D4 is now a direct trace. The 4k7
  attenuation killed the incoming 9600 baud signal. Keep the trace
  short; no series resistor is required at 3.3 V -> 5 V TTL for a
  short run.

v2.4 changes (bidirectional UART):
  - Added Heltec GPIO48 (L14) -> R6 (4k7) -> Nano D4 (R9) RX path
  - New nets: HELTEC_TX, D4
  - R6 series resistor protects Nano from back-feed when Heltec is
    USB-powered alone (flashing) while 5V rail is off

v2.2 changes (compact layout):
  - Board shrunk from 90x75mm to 75x66mm
  - R3/R4 moved from right of Nano to below Nano (X≈60, Y≈50)
  - Connectors J2/J3/J4 moved up to Y=62
  - V5/GND buses moved up (Y=55/57)
  - All routing updated for new positions
  - Mounting holes repositioned for smaller board

v2.1 changes (from expert DRC review):
  - Fixed VIN/5V short (removed V5 from Nano VIN pin)
  - GND drops routed on B.Cu via vias (eliminates track crossings)
  - D2 signal routed via B.Cu (fixes D2/GND short at RXB6)
  - 3V3 bus rerouted above components (fixes 3V3/pad shorts)
  - V5 feed uses B.Cu to cross GND bus
  - All text >= 0.8mm height, 0.15mm stroke (JLCPCB minimum)
  - Verbose notes moved to F.Fab layer
  - Added B.Mask and B.SilkS layers
  - 22 vias for proper 2-layer routing
"""

import os

def _build():
    P = 2.54  # standard pin pitch (mm)

    # ── Formatting ──────────────────────────────────────
    def f(v): return "{:.4f}".format(float(v))

    # ── Net registry ────────────────────────────────────
    _nets = {"": 0}; _nid = [0]
    def N(name):
        if name not in _nets: _nid[0] += 1; _nets[name] = _nid[0]
        return name
    GND = N("GND"); V5 = N("5V"); V5_IN = N("5V_IN"); V33 = N("3V3")
    D3_NET = N("D3"); D2_NET = N("D2")
    HLTC_RX = N("HELTEC_RX"); HLTC_TX = N("HELTEC_TX"); DE_NET = N("DE")

    _body = []
    def emit(s): _body.append(s)

    # ── Drawing primitives ──────────────────────────────
    MIN_TEXT = 0.8
    STROKE_W = 0.15

    def gr_line(x1, y1, x2, y2, layer="Edge.Cuts", w=0.05):
        emit(f'  (gr_line (start {f(x1)} {f(y1)}) (end {f(x2)} {f(y2)}) (layer "{layer}") (width {f(w)}))')

    def gr_circle(cx, cy, r, layer="F.CrtYd", w=0.05):
        emit(f'  (gr_circle (center {f(cx)} {f(cy)}) (end {f(cx+r)} {f(cy)}) (layer "{layer}") (width {f(w)}))')

    def gr_text(text, x, y, layer="F.SilkS", size=0.8, angle=0):
        sz = max(size, MIN_TEXT)
        ang = f' {f(angle)}' if angle else ""
        emit(f'  (gr_text "{text}" (at {f(x)} {f(y)}{ang}) (layer "{layer}")\n'
             f'    (effects (font (size {f(sz)} {f(sz)}) (thickness {f(STROKE_W)}))))')

    def silk(x1, y1, x2, y2, w=0.15):
        gr_line(x1, y1, x2, y2, "F.SilkS", w)

    def fab(x1, y1, x2, y2, w=0.10):
        gr_line(x1, y1, x2, y2, "F.Fab", w)

    def silk_box(x1, y1, x2, y2, w=0.15):
        for a, b in [((x1,y1),(x2,y1)), ((x2,y1),(x2,y2)),
                      ((x2,y2),(x1,y2)), ((x1,y2),(x1,y1))]:
            silk(a[0], a[1], b[0], b[1], w)

    def fab_box(x1, y1, x2, y2, w=0.10):
        for a, b in [((x1,y1),(x2,y1)), ((x2,y1),(x2,y2)),
                      ((x2,y2),(x1,y2)), ((x1,y2),(x1,y1))]:
            fab(a[0], a[1], b[0], b[1], w)

    def txt(text, x, y, size=0.8, layer="F.SilkS", angle=0):
        gr_text(text, x, y, layer, size, angle)

    def trk(x1, y1, x2, y2, net, layer="F.Cu", w=0.25):
        nid = _nets.get(net, 0)
        emit(f'  (segment (start {f(x1)} {f(y1)}) (end {f(x2)} {f(y2)})'
             f' (width {f(w)}) (layer "{layer}") (net {nid}))')

    def via_hole(x, y, net, drill=0.8, size=1.4):
        nid = _nets.get(net, 0)
        emit(f'  (via (at {f(x)} {f(y)}) (size {f(size)}) (drill {f(drill)})'
             f' (layers "F.Cu" "B.Cu") (net {nid}))')
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

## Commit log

2026-04-04 Initial commit — Gate Sensor Carrier PCB v2.2
    Meshtastic gate sensor carrier board (75x66mm, 2-layer) for
    Heltec LoRa32 V3 + Arduino Nano + RXB6 433MHz receiver.
    PCB: KiCad 10, generated by gate_sensor_pcb_v2.py, 0 DRC violations.
    Firmware: PlatformIO skeleton for ATmega328P bridge (RCSwitch + SoftwareSerial).
    Docs: schematic, BOM, assembly guide.
    [gate_sensor_v2.kicad_pcb]
2026-04-04 Fix stale D4/GPIO44 references from pre-review pin changes
    Rename D4_NET→D2_NET and D4_RXB_X→D2_RXB_X to match actual wiring
    (RXB6 DATA connects to Nano D2/INT0, not D4). Fix silkscreen text
    from GPIO44 to GPIO47 for Heltec serial RX pin.
    [gate_sensor_v2.kicad_pcb]
2026-04-04 PCB v2.3: remove battery monitoring, add 3D assembly view
    The Waveshare Solar Power Manager D handles battery internally —
    no BAT pin is accessible for voltage monitoring from the carrier PCB.
    PCB changes:
    - Remove R3, R4 (battery voltage divider) and J3 (battery connector)
    - Simplify V5 bus to straight run (no R4 notch)
    - Move R1/R2 right 2mm, restoring Heltec pins 40-42 to silkscreen
    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
    [gate_sensor_v2_assembly.kicad_pcb]
2026-04-05 Fix remaining stale D4 references in docs and comments
    The RF DATA net was renamed from D4 to D2 when the pin changed,
    but five documentation/comment locations still referenced D4.
    [gate_sensor_pcb_v2.py]
2026-04-05 Add JLCPCB ordering guide
    Step-by-step guide for ordering PCBs from JLCPCB: Gerber export,
    order form settings, and recommended options for the 2-layer board.
2026-04-05 Fix Arduino Nano left/right pin swap and digital pin order
    The Nano socket had analog/power pins on the RIGHT and digital pins
    on the LEFT — reversed from the real board. Digital pin order was also
    inverted (D1 at USB end instead of D12). Verified against 4 reference
    pinout images.
    - Swap NL/NR arrays: LEFT=analog/power, RIGHT=digital (descending)
    - Re-route D3 (R10→R1) all-F.Cu via top of board
    - Re-route D2 (R11→RXB6 DATA) all-F.Cu via right board edge
    - Simplify V5 routing: tap existing RXB6 B.Cu column at X=50
    - Update GND drops for new pin positions (L14, R12)
    - Trim V5 bus to end at last connection (X=50)
    - DRC: 0 violations, 0 unconnected pads
    [gate_sensor_v2.kicad_pcb, gate_sensor_v2_assembly.kicad_pcb]
2026-04-05 Fix D0/D1 label order on Nano right column
    CH340 Nano pinout images (3 of 4 references) show D1 above D0 at the
    bottom of the digital pin column. Swap silkscreen labels to match.
    No routing impact — neither pin has a net connected.
    [gate_sensor_v2.kicad_pcb, gate_sensor_v2_assembly.kicad_pcb]
2026-04-05 Adjust silkscreen labels: center socket names, add USB label to Nano
    - Move Heltec/Nano/RXB6 socket labels up for better vertical centering
    - Add "USB" label at top of Arduino Nano socket frame
    - Center R1 2k2 label above resistor body
    [gate_sensor_v2.kicad_pcb, gate_sensor_v2_assembly.kicad_pcb]
2026-04-05 Add Heltec Meshtastic flash script for gate sensor node
    Automates flash + configure workflow for Heltec V3 as gate sensor:
    - BAUD_9600 (matches Nano SoftwareSerial)
    - serial.rxd=47 (GPIO47, avoids CP2102 conflict)
    - serial.txd=0 (one-way UART, Nano does not receive)
    - Stock Meshtastic firmware (no custom build required)
    - Includes config verification step
    PSK loaded from .env file (not committed). See .env.example.
2026-04-05 Add PCB netlist verification test (34 checks)
    Validates net pad membership, forbidden connections, firmware pin
    mapping, Nano pin order (L/R swap regression), voltage divider
    correctness, and trace connectivity by parsing the generated KiCad
    PCB file. Run with: make test-netlist
    [test_netlist.py]
2026-04-05 Update JLCPCB ordering guide with all form options
    Cover every high-spec and advanced option in the order form:
    via plating, min via size, blind slots, UL marking, 4-wire Kelvin
    test, appearance quality, silkscreen technology, package box,
    inspection report, and PCB remark fields.
2026-04-16 Calibrate Nano firmware to KERUI D026 sensor
    - CODE_OPEN=150910 — decimal value learned from a real KERUI D026 via
    rc-switch.
    - CODE_CLOSED disabled: the sensor emits the same code on open and
    close, so no distinct close event is decodable. Emit "TRIGGERED"
    rather than "OPEN" to match that reality.
    - DEBOUNCE_MS raised from 200 to 10000 to collapse the KERUI retransmit
    burst (~5 repeats over a few seconds) into a single mesh message per
    physical opening.
    - platformio.ini: board=nanoatmega328new. Clone Nanos ship with
    optiboot @ 115200 baud; the old board=nanoatmega328 (57600) fails
    with stk500_getsync on flash.
    [config.h, main.cpp]
2026-04-16 Fix flash script after end-to-end bench test
    - Release asset naming: Meshtastic 2.7+ dropped the .factory.bin suffix,
    so the factory image is now firmware-heltec-v3-<ver>.bin and there is
    a sibling *-update.bin OTA delta that must NOT be flashed at 0x00.
    Update the glob to match the factory image and exclude the update
    image explicitly.
    - serial.txd=0 silently kills SerialModule RX on ESP32-S3: GPIO0 is the
    boot strap pin, and handing it to HardwareSerial::begin() fails the
    UART driver init, which also disables rxd. Park TX on an unused GPIO
    (48) so the driver initialises cleanly.
    - Set device owner (long=GateSensor, short=GATE) so the node shows up
    with a meaningful name in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
2026-04-16 Add sensor-learning workflow (docs + make target)
    Replaces the ambiguous "run the RCSwitch ReceiveDemo example" pointer
    in docs/assembly.md with a concrete procedure that reuses the already
    shipped firmware. Every RF hit that doesn't match CODE_OPEN is printed
    on USB serial as "RF unknown: <decimal>" — so the user just flashes
    the production firmware, triggers their new sensor, notes the
    repeating decimal, sets CODE_OPEN, and re-flashes.
    `make learn-sensor` prints the quick instructions and opens the serial
    monitor. Long-form guide in docs/learn-sensor.md covers retransmit
    bursts, open/close code equality, and debounce.
2026-04-16 Rewrite README: drop obsolete project reference, reflect current state
    - Drop the old project name from the title; this repo is a standalone
    meshtastic gate sensor.
    - PCB version 2.2 → 2.3 to match the current board and docs.
    - Expand the architecture paragraph to name the real signal chain
    (rc-switch on D2/INT0, SoftwareSerial D3, voltage divider into GPIO47,
    TEXTMSG mode at 9600 baud) and document the current message format
    (Gate: TRIGGERED, no distinct close event, 10 s debounce).
    - Add a Heltec flash-script invocation and a short description of what
    the script configures.
    - Add a learning-a-new-sensor section pointing at make learn-sensor and
    docs/learn-sensor.md.
    - Refresh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
2026-04-16 Sync assembly.md Phase 2/3 with current workflow
    Phase 2 now points at make learn-sensor (production firmware prints
    RF unknown: <decimal> on USB serial) instead of the old RCSwitch
    ReceiveDemo sketch. Default CODE_OPEN=150910 for KERUI D026 noted;
    CODE_CLOSED stays at 0 since the sensor emits the same code on
    open and close. Verify step shows Gate: TRIGGERED with the 10 s
    debounce behaviour.
    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
2026-04-16 PCB v2.3: move R5 silkscreen label to F.SilkS
    The R5 reference text was only placed on F.Fab in v2.2, so the
    physical board showed a resistor footprint with no printed label —
    easy to miss during assembly. Flip the label to F.SilkS and center
    it 3 mm above the body, matching the R1 convention. The verbose
    "DE pullup" note stays on F.Fab.
    The label needed to move above the resistor (Y - 3.0) rather than
    below (Y + 2.5): the first silk position clashed with the Heltec
    "6" GPIO label at (33.36, 50.31), and relocating further right
    then clashed with the RXB6 "DATA" pin-7 silk at (39.00, 49.77).
    Placing above the body clears both.
    DRC: 0 violations. Netlist self-test: 34/34 pass.
    pcb.md: ver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
    [gate_sensor_v2.kicad_pcb]
2026-04-16 Sync remaining docs with current firmware + PCB v2.3
    bom.md
    - Title reflects both cost variants (~$52 with solar, ~$36 bare)
    - Cost summary table added (with / bare / USB-C adapter)
    - Carrier PCB row bumped v2.2 → v2.3
    - R5 marked Optional (DNP): RXB6 DE pin floats high on its own
    with the batches this build has seen, so the pull-up is cheap
    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
2026-04-19 Replace fixed heartbeat with AntiHunter-compatible STATUS frame
    Drop the 5-min "GATE NODE: Online" fixed-string heartbeat and emit a
    STATUS frame instead, on boot and every 30 min. Shape matches the
    AntiHunter STATUS regex (meshtastic-rewrite.parser.ts:10 in CC PRO) so
    the frame parses cleanly in every portal in the ecosystem.
    Adds a trailing Type: field that carries the sensor-class identifier
    ("GATESENSOR" today, extensible to DOOR / MOTION / WINDOW on future
    builds). DigiNode CC classifies nodes purely on this value, not on the
    instance-name prefix, so a future "MotionHall" build can swap
    SENSOR_TYPE without touching the backend.
    Adds a persistent boot counter in EEPROM (2 bytes at addr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
    [config.h, main.cpp]
2026-04-19 PCB v2.4: add Heltec GPIO48 -> R6 -> Nano D4 RX path
    Enables bidirectional UART between the Heltec LoRa32 V3 and the Arduino
    Nano. The Nano can now receive Meshtastic serial frames in addition to
    sending RF events on D3.
    R6 (4.7k) sits in series on the new trace as a back-feed limiter: when
    the Heltec is USB-powered alone (e.g. during flashing) and the Nano's
    5V rail is off, GPIO48 driving HIGH would otherwise forward-bias the
    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
    [gate_sensor_v2.kicad_pcb, gate_sensor_v2_assembly.kicad_pcb]
2026-04-19 Firmware: CMD handler for STATUS, HB_ON, HB_OFF, HB_INTERVAL
    The Nano can now receive plain-text command frames over SoftwareSerial
    RX (D4, fed by Heltec GPIO48 through R6 from PCB v2.4). This enables
    remote operators (e.g. diginode-cc) to query and reconfigure the
    sensor without reflashing.
    Wire format: @<target> <verb>[:<param>...]\n
    Target is matched case-insensitively against ALL or SENSOR_NAME. Other
    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
2026-04-19 Firmware: REBOOT, HITS_RESET, DEBOUNCE_SET, dynamic code registry
    Adds domain-appropriate CMD verbs on top of the existing STATUS/HB_*
    framework and replaces the single compile-time 433 MHz code with a
    runtime-mutable list of up to 16 codes persisted in EEPROM.
    System:
    REBOOT watchdog-triggered soft reset; ACK-before-
    reset so the operator sees REBOOT_ACK:OK
    before the Nano drops off the mesh
    HITS_RESET zero the persistent hit counter
    DEBOUNCE_SET:<sec> retune the RF debounce window at runtime
    (1-60 s, persisted)
    Code registry:
    CODE_ADD:<decimal>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
    [config.h, main.cpp]
2026-04-19 PCB v2.4: silkscreen polish — logo 1.2x, text shift, layout tweaks
    - Scaled the bottom-right raccoon logo by 1.2x anchored at its
    top-left so the top edge stays in place and the previously empty
    space below the logo is filled. New logo bottom Y=65.1 still clears
    the 0.5 mm board-edge rule at Y=66.
    - Shifted the "GoTailMe.com / Meshtastic Gate / and Door Sensor" text
    block from X=54 to X=56 so the larger logo has breathing room.
    Clearance from logo right edge (X=48.7) to text left edge (~X=51.5)
    goes from 0.8 mm to 2.8 mm.
    - Existing silk polish already folded into the regenerated .kicad_pcb
    files: R6 "R6 4k7" label above the resistor (subtitle removed to
    free that space), a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
    [gate_sensor_v2.kicad_pcb, gate_sensor_v2_assembly.kicad_pcb]
2026-04-19 PCB v2.5: remove R6 (4k7) series resistor on Heltec→Nano RX path
    Bidirectional UART bring-up with Meshtastic Serial module (TEXTMSG
    mode) proved R6 attenuated the 3.3 V signal below the ATmega328P's
    V_IH threshold when running on 5 V logic — zero bytes reached D4
    until R6 was shorted out. Replace with a direct trace from Heltec
    GPIO48 to Nano D4.
    [gate_sensor_v2.kicad_pcb]
2026-04-19 PCB v2.5 cleanup: docs, netlist test, config comment, Makefile
    Sweep up remaining R6 references after the v2.5 direct-trace rework:
    - docs/schematic.md: remove R6 from block diagram and hardening
    components; rewrite the D4 net line as HELTEC_TX direct to U1-R9;
    fix a pre-existing typo where RXB6 pin 7 was listed on net D4
    instead of D2.
    - docs/firmware.md, docs/bom.md: drop R6 from library notes, pin
    table, BOM passives; bump carrier revision line to v2.5.
    - docs/pcb.md: remove R6 component row, rewrite HELTEC_TX routing
    paragraph, add v2.5 entry to the version history.
    - firmware/include/config.h: update the SERIAL_RX comment to match
    the direct trace.
    - pcb/test_netlist.py: dr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
    [config.h, generate_assembly.py, test_netlist.py]
2026-04-19 Firmware: strip Meshtastic TEXTMSG <sender>: prefix in processCmdLine
    The Heltec's Meshtastic Serial module prepends the sender's short-name
    (e.g. "1e44: @GATE HB_OFF") to every received broadcast in TEXTMSG
    mode, so the first char is a hex digit, not '@'. The old parser
    bailed when line[0] != '@' and silently dropped every inbound command.
    Search for '@' with strchr and advance past whatever precedes it.
    Pairs with PCB v2.5's direct GPIO48 -> D4 trace to close the loop
    end-to-end.
    [main.cpp]
2026-04-19 Firmware: 8s boot delay before first STATUS to let Heltec come up
    Nano boots in ~50ms; Meshtastic on the Heltec needs several seconds to
    bring up its Serial module. The boot STATUS was being fired into a dead
    UART and dropped.
2026-04-20 Makefile: auto-detect Nano FTDI port for upload/monitor
    Resolves the Nano via the persistent /dev/serial/by-id/usb-FTDI_FT232R_*
    symlink so pio doesn't pick a co-plugged Heltec's CP2102 (which yields
    "avrdude: not in sync" with random Meshtastic log bytes). Errors out if
    zero or multiple FTDI devices are present.
2026-04-20 docs/firmware: call out DM dead end, broadcasts only
    Adds a callout in the CMD Protocol section explaining why direct
    messages can't reach the Nano (Meshtastic SerialModule TEXTMSG mode
    stopped forwarding DMs to UART in fw 2.5) and how DigiNode CC's
    chat-send rewrites DMs as @<ShortName> broadcasts on the user's behalf.
2026-04-20 3dcase: add v1 housing Fusion 360 source and STL
    [gatesensor-v1.f3d, gatesensor-v1.stl]
2026-04-20 Firmware: named codes, TRIGGERED format, per-code debounce
    - EEPROM-backed parallel name table (16 slots × 16 bytes) with
    CODE_ADD:<code>[:<name>] / CODE_REMOVE / CODE_LIST / CODE_CLEAR.
    - New frame format "Gate: TRIGGERED:<code> <name>" (name="unnamed" when
    absent), replacing the old EVENT:<code>.
    - Unknown codes ≥ UNKNOWN_MIN_CODE broadcast with name "unknown"; short
    bursts stay on USB debug only.
    - RF debounce is now per-code (codeLastEvent[MAX_CODES]) so two different
    known codes can fire back-to-back. Unknown-code chatter still shares
    one lastUnknownEvent window to keep 433 MHz noise off the mesh.
    [config.h, main.cpp]
2026-05-02 Heltec flash: add --standalone retail mode (public PSK + BLE on)
    The default flow flashes a private PSK from .env and disables Bluetooth
    — right for developer/private-mesh deployments but wrong for retail. A
    unit going to a first-time buyer should join the public LongFast channel
    out of the box (so any stock Meshtastic node sees it without setup) and
    keep BLE enabled so the buyer can pair the Meshtastic mobile app and
    generate their own private PSK from there.
    `--standalone` skips the `--ch-set psk` and `bluetooth.enabled false`
    config commands, drops the .env / MESH_PSK requirement, and flips the
    verification matrix (PSK must equal AQ==, BLE must be true). Banner,
    help, and summary text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
2026-05-02 docs: add User and Technical Handbook
    User Handbook (~15 pages) walks a buyer through first boot on the
    public LongFast channel, switching to a private PSK over BLE, the @Gate
    command set (CODE_*/HB_*/DEBOUNCE/HITS/REBOOT/STATUS), the broadcast-
    only constraint (no DMs), tuning, mounting, and troubleshooting. Power
    section covers USB-C / batteries / optional solar; the printed enclosure
    is indoor-only. Written for the --standalone shipping state.
    Technical Handbook (~22 pages) consolidates pcb.md, schematic.md,
    firmware.md, assembly.md, and ordering.md for builders/modifiers:
    architecture, PCB v2.5 layout and divider math, full pin map, firmware
    setup/loop walkthrough with source line refs,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
